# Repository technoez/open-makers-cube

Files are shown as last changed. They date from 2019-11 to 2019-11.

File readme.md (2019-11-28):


# OpenMakersCube

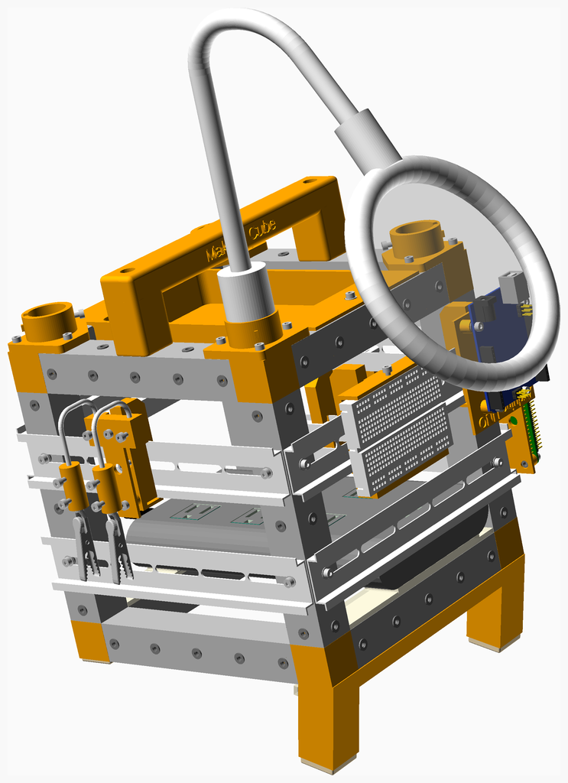
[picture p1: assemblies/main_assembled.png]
 <br>
**Open Maker's Cube** is an open source project developed for making electronics project design and testing more fun and convenient. Due to its versatile design, the Maker's Cube can be used for other hobbies and applications.

The itch needing scratching is the ratsnest of wires and cables generated when building electronics bread board circuits. I frequently use Raspberry Pis and other microcontrollers/SBCs.  With these devices comes the need for power strips which quickly leads to a maze of entangled power cords.

Portability of any electronics project can be an issue.  If a project is built on the kitchen table for example, relocating requires a lot of disconnecting and re-routing.  Inevetibly wires came loose from the breadboards, resulting in needless troubleshooting.

Ergonomically, bending over and wiring breadboard circuits for hours is hard on the back and neck.  Adequate Lighting can also be a concern.

The Maker's cube is lightweight. Around 3.5 lbs base unit only and is less than 7 lbs fully loaded with hardware(Rpi's/Arduinos, electronic components, plugin power supplies).

The dimensions are 200mm (8in.) x 200mm (8in.) x 200mm (8in.).  This size is perfect for any desk or table.  Not taking up any more space than a typical laptop.

The frame is made out of lightweight 1 in. square aluminum tubing. In early designs, 80/20 was used, but added almost 2x the weight.

M3 Threaded aluminum inserts are inserted into the aluminum frame to hold the components securely. The threaded inserts do require a rivet insertion tool. There are a lot of rivets, so inserting rivets into the frame is the most time consuming process. 

All plastic parts (orange) are printed with PETG. I went with PETG to hopefully withstand the heat better. Especially in the summer months. Obviously, print in any material to fit your needs.

There are mounting plates to support Raspberry PIs and Arduino UNOs in both landscape and portrait orientations.  Due to the flexibility of the DIN Rail clips, you can design any mounting plate for any device which can easily be attached to the DIN rail clips using two 2 - 3mm securing screws.

There is a mounting plate which holds a standard 400 pt solderless breadboard in both landscape and portrait orientations.

Mounted in the center of the Maker's cube is a 6 outlet power strip with 4 - 2.4A USB ports. This allows for mulitple electrical plugins inside the cube keeping the corded 'ratsnest' inside the body of the cube.  The power strip has an extra long 9.8 ft cord.

By design, only M3 screws are used.  This requires only a simple 2.5mm allen key, which I leave inside the tray.  The DIN rail mounting clips can normally be removed by hand.  However, if there are a lot of mounted components, the only other tool needed is a small flat tipped screwdriver to unlock the clips.

I use 6 inch plastic wire ties to keep the cables/wires organized inside the Maker's cube body.

There is a removable stand (prop) which is used to tilt the cube back at a 30 deg angle which allows the user to work at a comfortable eye level.

The detachable LED magnifier lamp is extremely handy.  It is super bright and having a magnifier lens makes it extremely easy to see the intricate details.

As an after thought, I designed a crude helping hands assembly.  It uses 3mm aluminum armature wire and conventional alligator clips.  This is helpful if you need to solder or hold components.  Yes, the wire will eventually break with excessive bending back-and-forth, but the wire is cheap and can be easily replaced. 

I use 3M's 'Dual Lock' fastener tape to secure the power supply to the inside bottom frame of the cube.  The allows the power supply to be easily removed if need be.  Also, the front 'prop' stand which tilts the cube at an angle, uses small sections of this tape to secure itself inside the cube's inner frame for transport.

To be extremely modular and flexible I designed the DIN Rail clips to be generic by nature. There two 3mm threaded inserts for mounting external components. The idea is you can design and mount anything you'd like to the clip.  

I began the CAD design work in Sketchup. However, since I wanted to release as a open source project, I migrated the CAD design over to [OpenScad](http://openscad.org).  I relied heavlily on these wonderful open source projects:  
1. [NopSCADlib](https://github.com/nophead/NopSCADlib/blob/master/readme.md) - nophead, thanks so much for contributing this library! Absolutely amazing and a huge time saver for generating this beautiful documentation.
2. [BOSL](https://github.com/revarbat/BOSL/wiki) 
3. [Dimlines - A dimensioning library](http://www.cannymachines.com/entries/9/openscad_dimensioned_drawings)
4. [objectarrays](https://github.com/mathcodeprint/openscad-fiddlybits/blob/master/objectarrays.scad)
5. [MCAD](https://github.com/openscad/MCAD)
6. [Obiscad](https://github.com/Obijuan/obiscad)
7. [Textgenerator](https://www.thingiverse.com/thing:59817)
8. [Shimonbox](https://github.com/ubitux/shimonbox)
9. [Openscad-threads](http://dkprojects.net/openscad-threads/)
10. [Chamfersfor OpenScad](https://github.com/SebiTimeWaster/Chamfers-for-OpenSCAD)
11. [BOLTS](https://www.bolts-library.org/en/index.html)
12. [Din Rail Inspiration](https://www.thingiverse.com/thing:101024) RobertHunt Thingiverse

Thank you to the authors of these libraries. I may not have used all them directly in this project, but have gained inspiration from all. 
I may have used other libraries which I have not given credit. If so, please contact me and I'll update the list. 
I'm relatively new to OpenScad programming, so my code is not perfect and not always fully parameterized.

In summary, Maker's Cube goal is to address the following concerns:
1. **Portability**
   Contain the electronics project in one location and easy to transport. A fully loaded cube weighs less than 6 lbs.
2. **Less back strain** 
   You can comfortably work on your projects in a seated position, eliminating the need to bend over a table/desk for hours.
3. **Less eye strain**
   There is a flexible super bright LED lamp mounted to the cube with a 1.5X magnifier glass.
4. **Modularity**
   Due to the Clip-on DIN Rail system, components can be easily re-positioned/removed from the cube.
5. **Project tidyness**
   A 6 outlet power strip with 4 - 2.4A USB ports is located inside the base of the cube. 
   This allows for mulitple electrical plugins inside the cube keeping the corded 'ratsnest' inside the body of the cube.

### Tools Required For Build:
1. 3D Printer
2. [Threaded Insert Rivet Gun w/3mm mandrel](https://www.amazon.com/gp/product/B06XVB3MMG/ref=ppx_yo_dt_b_search_asin_title?ie=UTF8&psc=1)
3. 2.5mm Allen Key
4. Saw to Cut 1 in. aluminum tubing.  Chopsaw, hacksaw, other.
5. Knife or razor blades
6. 5mm drill bit to drill holes for 3mm threaded inserts
7. Drill    
8. 3mm x .5mm hole tap.  To tap 3mm holes in 3D printed plastic.

### Parts List and Qty Per Build:
- [See Table Of Contents](readme.md#table-of-contents)

### Vendor List of Parts (aka vitamins):
- [M3 Threaded Rivet Inserts (bag 100pcs)](https://www.amazon.com/gp/product/B07HKK364C/ref=ppx_yo_dt_b_search_asin_title?ie=UTF8&psc=1)
- [Velcro - 3M Dual Lock 1in wide 6FT Long](https://www.amazon.com/gp/product/B07D2LYFM2/ref=ppx_yo_dt_b_search_asin_title?ie=UTF8&psc=1)
- [PETG Filament - Orange 1Kg (1080 FT long)](https://www.amazon.com/gp/product/B014VM9ALM/ref=ppx_yo_dt_b_asin_title_o00_s00?ie=UTF8&psc=1)
- [6 Outlet power strip (SuperDanny)](https://www.amazon.com/gp/product/B077ZSC6RQ/ref=ppx_yo_dt_b_search_asin_title?ie=UTF8&psc=1)
- [Breadboard - Half Size (pack 6 ea)](https://www.amazon.com/gp/product/B01NARN7SM/ref=ppx_yo_dt_b_search_asin_title?ie=UTF8&psc=1)
- [Rubber Bumpers (pack of 20 ea)](https://www.amazon.com/gp/product/B01G5WX4M2/ref=ppx_yo_dt_b_search_asin_title?ie=UTF8&psc=1)
- [Screws - M3 x 5 (pack of 100)](https://www.boltdepot.com/Product-Details.aspx?product=6377)
- [Screws - M3 x 8](https://www.boltdepot.com/Product-Details.aspx?product=6379)
- [Screws - M3 x 12](https://www.boltdepot.com/Product-Details.aspx?product=6381)
- [Screws - M3 x 16](https://www.boltdepot.com/Product-Details.aspx?product=6382)
- [Washers - M3](https://www.boltdepot.com/Product-Details.aspx?product=4513)
- [Magnifier Lamp](https://www.amazon.com/gp/product/B019R1BN3U/ref=ppx_yo_dt_b_search_asin_title?ie=UTF8&psc=1)
- [Armature Wire 3MM (32.8 ft copper/alum)](https://www.amazon.com/gp/product/B07CQL7Y5B/ref=ppx_yo_dt_b_search_asin_title?ie=UTF8&psc=1)
- [Tygon Tubing 50FT 1/8" OD (cover alligator clips)](https://www.zoro.com/tygon-tubing-clear-18-in-inside-dia-50-ft-acf00006/i/G4124294/)
- [Alligator Clips (Package of 50)](https://www.amazon.com/gp/product/B01D9BO4OO/ref=ppx_yo_dt_b_search_asin_title?ie=UTF8&psc=1)
- [Plastic Ties Blk 6 in (pk 250)](https://www.amazon.com/gp/product/B0718T3FMF/ref=ppx_yo_dt_b_search_asin_title?ie=UTF8&psc=1)
- [2.5MM Allen Wrench (pk 100)](https://www.amazon.com/gp/product/B005SE78Z8/ref=ppx_yo_dt_b_search_asin_title?ie=UTF8&psc=1)
- [Din Rails 200MM (20 Pak)](https://www.amazon.com/gp/product/B07HMW318D/ref=ppx_yo_dt_b_asin_title_o08_s00?ie=UTF8&psc=1)

### Picture Gallery 
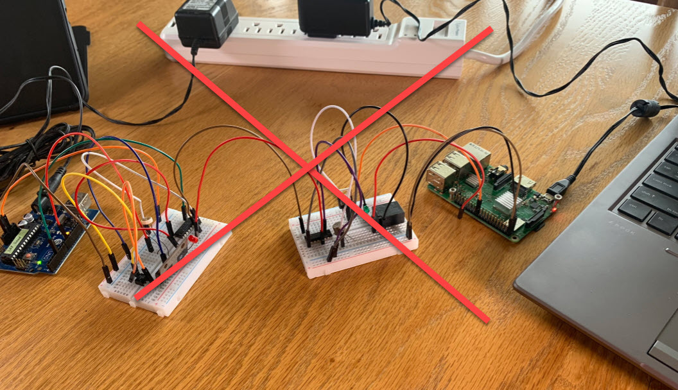
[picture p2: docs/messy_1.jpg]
- 
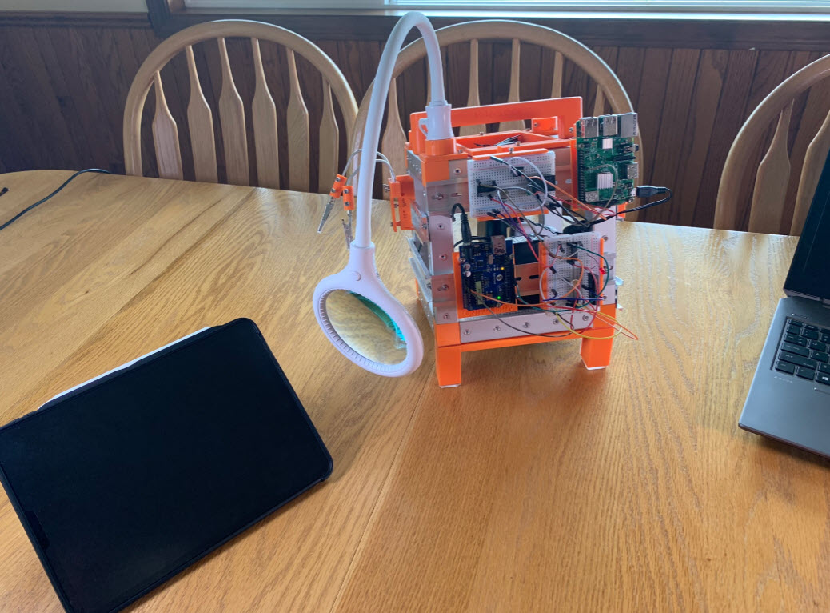
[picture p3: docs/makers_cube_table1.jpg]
- 
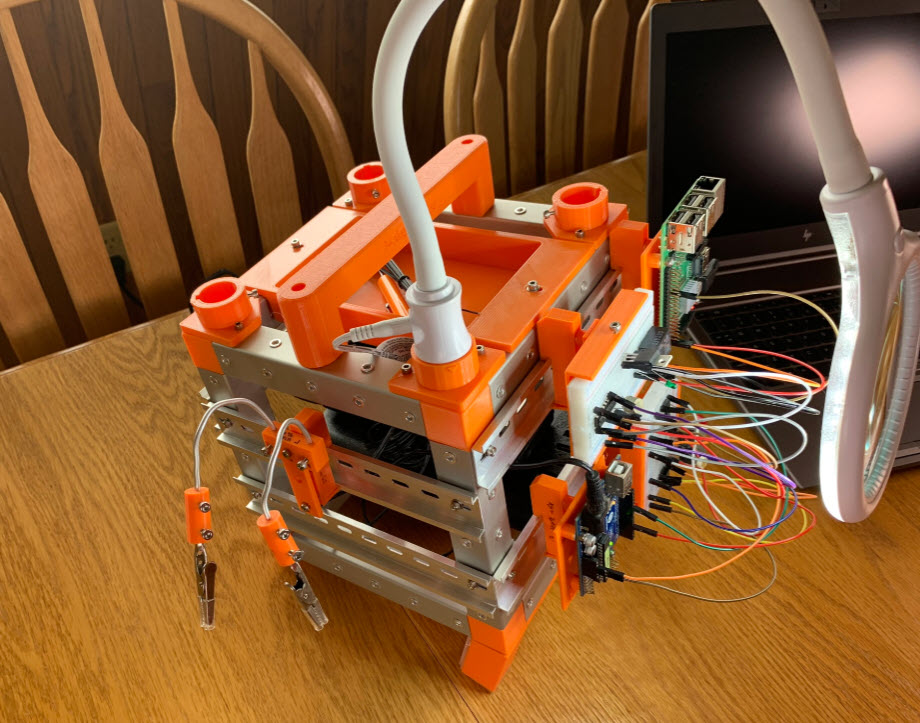
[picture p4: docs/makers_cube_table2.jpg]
- 
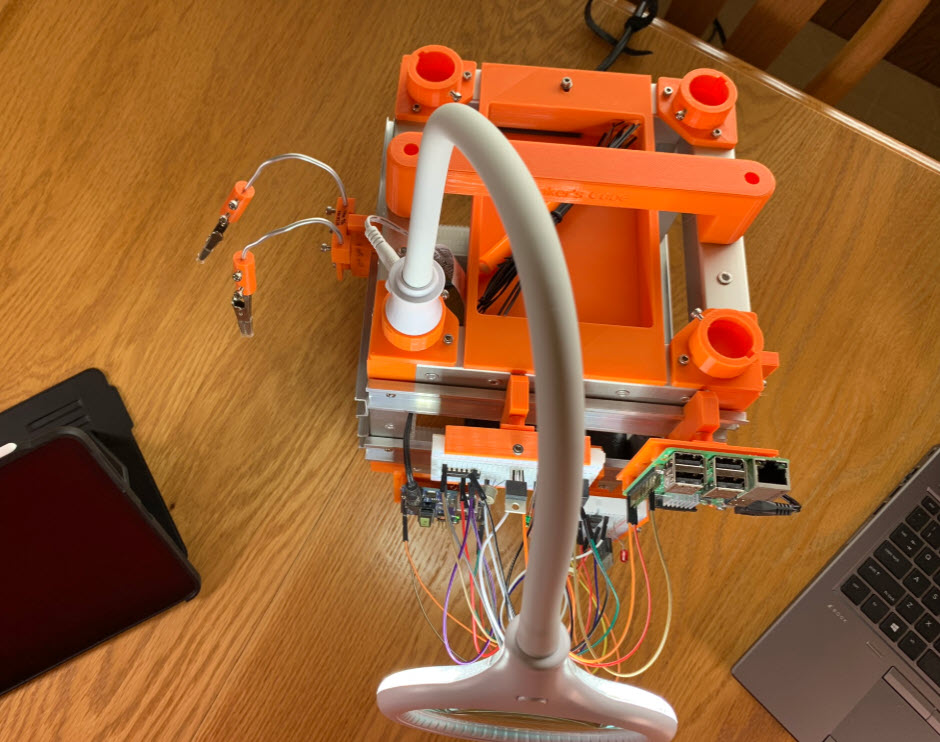
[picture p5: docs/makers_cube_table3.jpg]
- 
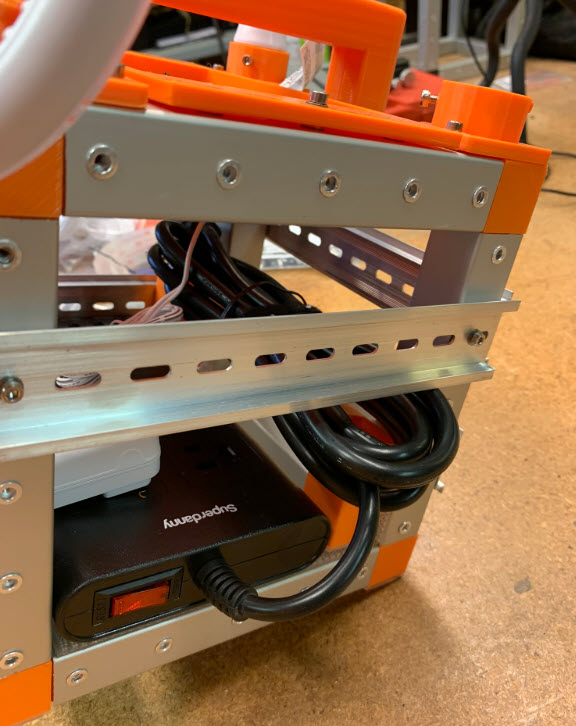
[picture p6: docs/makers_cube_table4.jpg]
- 
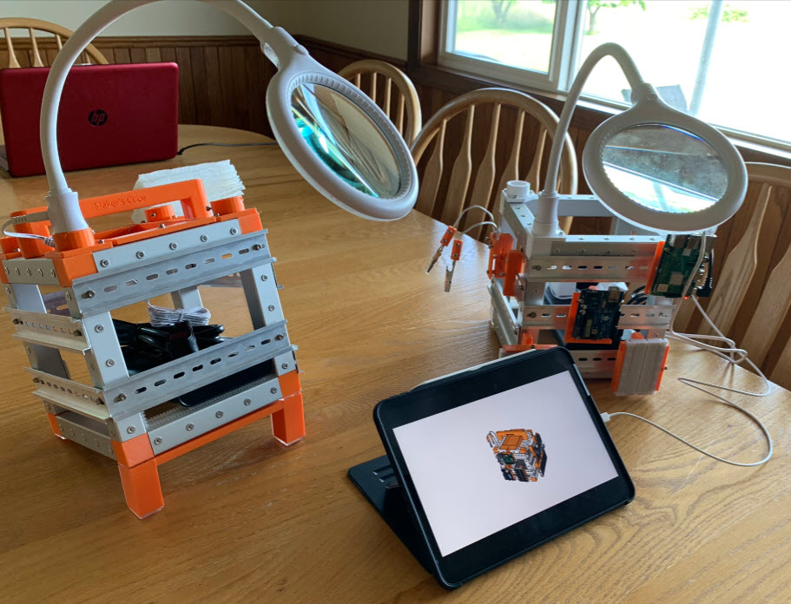
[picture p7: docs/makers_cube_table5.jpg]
- 
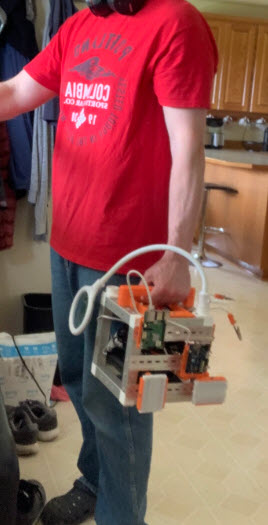
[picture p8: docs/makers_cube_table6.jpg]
- 

### 3D Printing
All of the STL models for this project are located in the /stls subdirectory.

Getting these prints correct was a highly iterative process.  Accuracy is the key to getting these components to fit properly.
Make sure your printer is calibrated and X/Y print scaling is correct.

### 3D Print Settings
<table>
<tr><th>STL</th><th>Resolution</th><th>Infill %</th><th>Supports</th><th>Comments</th></tr>
<tr><td>arduino_uno_mounting_plate.stl</td><td align="center">.3</td><td align="center">20</td><td align="center">NO</td><td>STL file located in <b>/stls</b> directory</td></tr>
<tr><td>armature_union.stl</td><td align="center">.3</td><td align="center">100</td><td align="center">NO</td><td>STL file located in <b>/stls</b> directory</td></tr>
<tr><td>back_spin_plate.stl</td><td align="center">.3</td><td align="center">20</td><td align="center">NO</td><td>STL file located in <b>/stls</b> directory</td></tr>
<tr><td>carry_handle.stl</td><td align="center">.3</td><td align="center">20</td><td align="center">NO</td><td>STL file located in <b>/stls</b> directory</td></tr>
<tr><td>corner_tube_connector_bottom.stl</td><td align="center">.3</td><td align="center">20</td><td align="center"><b>YES</b></td><td>STL file located in <b>/stls</b> directory</td></tr>
<tr><td>corner_tube_connector_bottom_v2.stl</td><td align="center">.3</td><td align="center">20</td><td align="center">NO</td><td>Alternate print orientation not requiring supports and stronger. STL file located in <b>/docs</b> directory</td></tr>
<tr><td>corner_tube_connector_top.stl</td><td align="center">.3</td><td align="center">20</td><td align="center"><b>YES</b></td><td>STL file located in <b>/stls</b> directory</td></tr>
<tr><td>corner_tube_connector_top_v2.stl</td><td align="center">.3</td><td align="center">20</td><td align="center">NO</td><td>Alternate print orientation not requiring supports and stronger. STL file located in <b>/docs</b> directory</td></tr>
<tr><td>din_rail_clip.stl</td><td align="center">.3</td><td align="center">100</td><td align="center">NO</td><td>STL file located in <b>/stls</b> directory</td></tr>
<tr><td>helping_hands_mount.stl</td><td align="center">.3</td><td align="center">20</td><td align="center">NO</td><td>STL file located in <b>/stls</b> directory</td></tr>
<tr><td>prop.stl</td><td align="center">.3</td><td align="center">20</td><td align="center">NO</td><td>STL file located in <b>/stls</b> directory</td></tr>
<tr><td>raspberry_pi_mounting_plate.stl</td><td align="center">.3</td><td align="center">20</td><td align="center">NO</td><td>STL file located in <b>/stls</b> directory</td></tr>
<tr><td>small_breadboard_holder.stl</td><td align="center">.3</td><td align="center">20</td><td align="center">NO</td><td>STL file located in <b>/stls</b> directory</td></tr>
</table>

Main Assembly

---
## Table of Contents
1. [Parts list](#Parts_list)
1. [Prop Assembly](#prop_assembly)
1. [Power Strip Assembly](#power_strip_assembly)
1. [Tray Assembly](#tray_assembly)
1. [Corner Lamp Holder Assembly](#corner_lamp_holder_assembly)
1. [Din Rail Clip Assembly](#din_rail_clip_assembly)
1. [Back Spin Plate Assembly](#back_spin_plate_assembly)
1. [Raspberry Pi Mounting Plate Portrait Assembly](#raspberry_pi_mounting_plate_portrait_assembly)
1. [Arduino Uno Mounting Plate Portrait Assembly](#arduino_uno_mounting_plate_portrait_assembly)
1. [Small Breadboard Portrait Assembly](#small_breadboard_portrait_assembly)
1. [Small Breadboard Landscape Assembly](#small_breadboard_landscape_assembly)
1. [Carry Handle Assembly](#carry_handle_assembly)
1. [Din Rail Assembly](#din_rail_assembly)
1. [Corner Tube Top Assembly](#corner_tube_top_assembly)
1. [Frame Bottom Assembly](#frame_bottom_assembly)
1. [Frame Middle Assembly](#frame_middle_assembly)
1. [Frame Top Assembly](#frame_top_assembly)
1. [Frame Assembly](#frame_assembly)
1. [Helping Hands Assembly](#helping_hands_assembly)
1. [Main Assembly](#main_assembly)

[Top](#TOP)

---

## Parts list
| <span style="writing-mode: vertical-rl; text-orientation: mixed;">Prop</span> | <span style="writing-mode: vertical-rl; text-orientation: mixed;">Power&nbsp;Strip</span> | <span style="writing-mode: vertical-rl; text-orientation: mixed;">Tray</span> | <span style="writing-mode: vertical-rl; text-orientation: mixed;">Corner&nbsp;Lamp&nbsp;Holder</span> | <span style="writing-mode: vertical-rl; text-orientation: mixed;">Din&nbsp;Rail&nbsp;Clip</span> | <span style="writing-mode: vertical-rl; text-orientation: mixed;">Back&nbsp;Spin&nbsp;Plate</span> | <span style="writing-mode: vertical-rl; text-orientation: mixed;">Raspberry&nbsp;Pi&nbsp;Mounting&nbsp;Plate&nbsp;Portrait</span> | <span style="writing-mode: vertical-rl; text-orientation: mixed;">Arduino&nbsp;Uno&nbsp;Mounting&nbsp;Plate&nbsp;Portrait</span> | <span style="writing-mode: vertical-rl; text-orientation: mixed;">Small&nbsp;Breadboard&nbsp;Portrait</span> | <span style="writing-mode: vertical-rl; text-orientation: mixed;">Small&nbsp;Breadboard&nbsp;Landscape</span> | <span style="writing-mode: vertical-rl; text-orientation: mixed;">Carry&nbsp;Handle</span> | <span style="writing-mode: vertical-rl; text-orientation: mixed;">Din&nbsp;Rail</span> | <span style="writing-mode: vertical-rl; text-orientation: mixed;">Corner&nbsp;Tube&nbsp;Top</span> | <span style="writing-mode: vertical-rl; text-orientation: mixed;">Frame&nbsp;Bottom</span> | <span style="writing-mode: vertical-rl; text-orientation: mixed;">Frame&nbsp;Middle</span> | <span style="writing-mode: vertical-rl; text-orientation: mixed;">Frame&nbsp;Top</span> | <span style="writing-mode: vertical-rl; text-orientation: mixed;">Frame</span> | <span style="writing-mode: vertical-rl; text-orientation: mixed;">Helping&nbsp;Hands</span> | <span style="writing-mode: vertical-rl; text-orientation: mixed;">Main</span> | <span style="writing-mode: vertical-rl; text-orientation: mixed;">TOTALS</span> |  |
|--:|--:|--:|--:|--:|--:|--:|--:|--:|--:|--:|--:|--:|--:|--:|--:|--:|--:|--:|--:|:--|
| &nbsp;&nbsp;.&nbsp; | &nbsp;&nbsp;.&nbsp; | &nbsp;&nbsp;.&nbsp; | &nbsp;&nbsp;.&nbsp; | &nbsp;&nbsp;.&nbsp; | &nbsp;&nbsp;.&nbsp; | &nbsp;&nbsp;.&nbsp; | &nbsp;&nbsp;.&nbsp; | &nbsp;&nbsp;.&nbsp; | &nbsp;&nbsp;.&nbsp; | &nbsp;&nbsp;.&nbsp; | &nbsp;&nbsp;.&nbsp; | &nbsp;&nbsp;.&nbsp; | &nbsp;&nbsp;.&nbsp; | &nbsp;&nbsp;.&nbsp; | &nbsp;&nbsp;.&nbsp; | &nbsp;&nbsp;.&nbsp; | &nbsp;&nbsp;.&nbsp; | &nbsp;&nbsp;2&nbsp; |  &nbsp;&nbsp;2&nbsp; | &nbsp;&nbsp;  3M Dual lock velcro 149mm long |
| &nbsp;&nbsp;2&nbsp; | &nbsp;&nbsp;.&nbsp; | &nbsp;&nbsp;.&nbsp; | &nbsp;&nbsp;.&nbsp; | &nbsp;&nbsp;.&nbsp; | &nbsp;&nbsp;.&nbsp; | &nbsp;&nbsp;.&nbsp; | &nbsp;&nbsp;.&nbsp; | &nbsp;&nbsp;.&nbsp; | &nbsp;&nbsp;.&nbsp; | &nbsp;&nbsp;.&nbsp; | &nbsp;&nbsp;.&nbsp; | &nbsp;&nbsp;.&nbsp; | &nbsp;&nbsp;.&nbsp; | &nbsp;&nbsp;.&nbsp; | &nbsp;&nbsp;.&nbsp; | &nbsp;&nbsp;.&nbsp; | &nbsp;&nbsp;.&nbsp; | &nbsp;&nbsp;2&nbsp; |  &nbsp;&nbsp;4&nbsp; | &nbsp;&nbsp;  3M Dual lock velcro 6mm long |
| &nbsp;&nbsp;.&nbsp; | &nbsp;&nbsp;2&nbsp; | &nbsp;&nbsp;.&nbsp; | &nbsp;&nbsp;.&nbsp; | &nbsp;&nbsp;.&nbsp; | &nbsp;&nbsp;.&nbsp; | &nbsp;&nbsp;.&nbsp; | &nbsp;&nbsp;.&nbsp; | &nbsp;&nbsp;.&nbsp; | &nbsp;&nbsp;.&nbsp; | &nbsp;&nbsp;.&nbsp; | &nbsp;&nbsp;.&nbsp; | &nbsp;&nbsp;.&nbsp; | &nbsp;&nbsp;.&nbsp; | &nbsp;&nbsp;.&nbsp; | &nbsp;&nbsp;.&nbsp; | &nbsp;&nbsp;.&nbsp; | &nbsp;&nbsp;.&nbsp; | &nbsp;&nbsp;.&nbsp; |  &nbsp;&nbsp;2&nbsp; | &nbsp;&nbsp;  3M Dual lock velcro 85mm long |
| &nbsp;&nbsp;.&nbsp; | &nbsp;&nbsp;1&nbsp; | &nbsp;&nbsp;.&nbsp; | &nbsp;&nbsp;.&nbsp; | &nbsp;&nbsp;.&nbsp; | &nbsp;&nbsp;.&nbsp; | &nbsp;&nbsp;.&nbsp; | &nbsp;&nbsp;.&nbsp; | &nbsp;&nbsp;.&nbsp; | &nbsp;&nbsp;.&nbsp; | &nbsp;&nbsp;.&nbsp; | &nbsp;&nbsp;.&nbsp; | &nbsp;&nbsp;.&nbsp; | &nbsp;&nbsp;.&nbsp; | &nbsp;&nbsp;.&nbsp; | &nbsp;&nbsp;.&nbsp; | &nbsp;&nbsp;.&nbsp; | &nbsp;&nbsp;.&nbsp; | &nbsp;&nbsp;.&nbsp; |  &nbsp;&nbsp;1&nbsp; | &nbsp;&nbsp;  Super Danny 6 outlet Power Strip |
| &nbsp;&nbsp;2&nbsp; | &nbsp;&nbsp;.&nbsp; | &nbsp;&nbsp;.&nbsp; | &nbsp;&nbsp;.&nbsp; | &nbsp;&nbsp;.&nbsp; | &nbsp;&nbsp;.&nbsp; | &nbsp;&nbsp;.&nbsp; | &nbsp;&nbsp;.&nbsp; | &nbsp;&nbsp;.&nbsp; | &nbsp;&nbsp;.&nbsp; | &nbsp;&nbsp;.&nbsp; | &nbsp;&nbsp;.&nbsp; | &nbsp;&nbsp;.&nbsp; | &nbsp;&nbsp;.&nbsp; | &nbsp;&nbsp;.&nbsp; | &nbsp;&nbsp;.&nbsp; | &nbsp;&nbsp;.&nbsp; | &nbsp;&nbsp;.&nbsp; | &nbsp;&nbsp;4&nbsp; |  &nbsp;&nbsp;6&nbsp; | &nbsp;&nbsp; 1 inch sq rubber foot |
| &nbsp;&nbsp;.&nbsp; | &nbsp;&nbsp;.&nbsp; | &nbsp;&nbsp;.&nbsp; | &nbsp;&nbsp;.&nbsp; | &nbsp;&nbsp;.&nbsp; | &nbsp;&nbsp;.&nbsp; | &nbsp;&nbsp;.&nbsp; | &nbsp;&nbsp;.&nbsp; | &nbsp;&nbsp;.&nbsp; | &nbsp;&nbsp;.&nbsp; | &nbsp;&nbsp;.&nbsp; | &nbsp;&nbsp;.&nbsp; | &nbsp;&nbsp;.&nbsp; | &nbsp;&nbsp;4&nbsp; | &nbsp;&nbsp;4&nbsp; | &nbsp;&nbsp;4&nbsp; | &nbsp;&nbsp;.&nbsp; | &nbsp;&nbsp;.&nbsp; | &nbsp;&nbsp;.&nbsp; |  &nbsp;&nbsp;12&nbsp; | &nbsp;&nbsp; 1IN Aluminum Square Tube 149.2 MM long |
| &nbsp;&nbsp;.&nbsp; | &nbsp;&nbsp;.&nbsp; | &nbsp;&nbsp;.&nbsp; | &nbsp;&nbsp;.&nbsp; | &nbsp;&nbsp;.&nbsp; | &nbsp;&nbsp;.&nbsp; | &nbsp;&nbsp;.&nbsp; | &nbsp;&nbsp;.&nbsp; | &nbsp;&nbsp;.&nbsp; | &nbsp;&nbsp;.&nbsp; | &nbsp;&nbsp;.&nbsp; | &nbsp;&nbsp;7&nbsp; | &nbsp;&nbsp;.&nbsp; | &nbsp;&nbsp;.&nbsp; | &nbsp;&nbsp;.&nbsp; | &nbsp;&nbsp;.&nbsp; | &nbsp;&nbsp;.&nbsp; | &nbsp;&nbsp;.&nbsp; | &nbsp;&nbsp;.&nbsp; |  &nbsp;&nbsp;7&nbsp; | &nbsp;&nbsp; 35MM Din Rail 200 MM long |
| &nbsp;&nbsp;.&nbsp; | &nbsp;&nbsp;.&nbsp; | &nbsp;&nbsp;.&nbsp; | &nbsp;&nbsp;.&nbsp; | &nbsp;&nbsp;.&nbsp; | &nbsp;&nbsp;.&nbsp; | &nbsp;&nbsp;.&nbsp; | &nbsp;&nbsp;.&nbsp; | &nbsp;&nbsp;.&nbsp; | &nbsp;&nbsp;.&nbsp; | &nbsp;&nbsp;.&nbsp; | &nbsp;&nbsp;.&nbsp; | &nbsp;&nbsp;.&nbsp; | &nbsp;&nbsp;.&nbsp; | &nbsp;&nbsp;.&nbsp; | &nbsp;&nbsp;.&nbsp; | &nbsp;&nbsp;.&nbsp; | &nbsp;&nbsp;2&nbsp; | &nbsp;&nbsp;.&nbsp; |  &nbsp;&nbsp;2&nbsp; | &nbsp;&nbsp; 3MM Armature wire - 5 inches long |
| &nbsp;&nbsp;.&nbsp; | &nbsp;&nbsp;.&nbsp; | &nbsp;&nbsp;.&nbsp; | &nbsp;&nbsp;.&nbsp; | &nbsp;&nbsp;8&nbsp; | &nbsp;&nbsp;8&nbsp; | &nbsp;&nbsp;4&nbsp; | &nbsp;&nbsp;4&nbsp; | &nbsp;&nbsp;.&nbsp; | &nbsp;&nbsp;.&nbsp; | &nbsp;&nbsp;.&nbsp; | &nbsp;&nbsp;.&nbsp; | &nbsp;&nbsp;4&nbsp; | &nbsp;&nbsp;20&nbsp; | &nbsp;&nbsp;40&nbsp; | &nbsp;&nbsp;40&nbsp; | &nbsp;&nbsp;.&nbsp; | &nbsp;&nbsp;.&nbsp; | &nbsp;&nbsp;.&nbsp; |  &nbsp;&nbsp;128&nbsp; | &nbsp;&nbsp; 3MM threaded rivet insert |
| &nbsp;&nbsp;.&nbsp; | &nbsp;&nbsp;.&nbsp; | &nbsp;&nbsp;.&nbsp; | &nbsp;&nbsp;.&nbsp; | &nbsp;&nbsp;.&nbsp; | &nbsp;&nbsp;.&nbsp; | &nbsp;&nbsp;.&nbsp; | &nbsp;&nbsp;.&nbsp; | &nbsp;&nbsp;.&nbsp; | &nbsp;&nbsp;.&nbsp; | &nbsp;&nbsp;.&nbsp; | &nbsp;&nbsp;.&nbsp; | &nbsp;&nbsp;.&nbsp; | &nbsp;&nbsp;.&nbsp; | &nbsp;&nbsp;.&nbsp; | &nbsp;&nbsp;.&nbsp; | &nbsp;&nbsp;.&nbsp; | &nbsp;&nbsp;2&nbsp; | &nbsp;&nbsp;.&nbsp; |  &nbsp;&nbsp;2&nbsp; | &nbsp;&nbsp; Alligator Clip |
| &nbsp;&nbsp;.&nbsp; | &nbsp;&nbsp;.&nbsp; | &nbsp;&nbsp;.&nbsp; | &nbsp;&nbsp;.&nbsp; | &nbsp;&nbsp;.&nbsp; | &nbsp;&nbsp;.&nbsp; | &nbsp;&nbsp;.&nbsp; | &nbsp;&nbsp;1&nbsp; | &nbsp;&nbsp;.&nbsp; | &nbsp;&nbsp;.&nbsp; | &nbsp;&nbsp;.&nbsp; | &nbsp;&nbsp;.&nbsp; | &nbsp;&nbsp;.&nbsp; | &nbsp;&nbsp;.&nbsp; | &nbsp;&nbsp;.&nbsp; | &nbsp;&nbsp;.&nbsp; | &nbsp;&nbsp;.&nbsp; | &nbsp;&nbsp;.&nbsp; | &nbsp;&nbsp;.&nbsp; |  &nbsp;&nbsp;1&nbsp; | &nbsp;&nbsp; Arduino Uno R3 |
| &nbsp;&nbsp;.&nbsp; | &nbsp;&nbsp;.&nbsp; | &nbsp;&nbsp;.&nbsp; | &nbsp;&nbsp;.&nbsp; | &nbsp;&nbsp;.&nbsp; | &nbsp;&nbsp;.&nbsp; | &nbsp;&nbsp;.&nbsp; | &nbsp;&nbsp;.&nbsp; | &nbsp;&nbsp;.&nbsp; | &nbsp;&nbsp;.&nbsp; | &nbsp;&nbsp;.&nbsp; | &nbsp;&nbsp;.&nbsp; | &nbsp;&nbsp;.&nbsp; | &nbsp;&nbsp;.&nbsp; | &nbsp;&nbsp;.&nbsp; | &nbsp;&nbsp;.&nbsp; | &nbsp;&nbsp;.&nbsp; | &nbsp;&nbsp;.&nbsp; | &nbsp;&nbsp;1&nbsp; |  &nbsp;&nbsp;1&nbsp; | &nbsp;&nbsp; Magnifier Lamp Assembly |
| &nbsp;&nbsp;.&nbsp; | &nbsp;&nbsp;.&nbsp; | &nbsp;&nbsp;.&nbsp; | &nbsp;&nbsp;.&nbsp; | &nbsp;&nbsp;.&nbsp; | &nbsp;&nbsp;.&nbsp; | &nbsp;&nbsp;1&nbsp; | &nbsp;&nbsp;.&nbsp; | &nbsp;&nbsp;.&nbsp; | &nbsp;&nbsp;.&nbsp; | &nbsp;&nbsp;.&nbsp; | &nbsp;&nbsp;.&nbsp; | &nbsp;&nbsp;.&nbsp; | &nbsp;&nbsp;.&nbsp; | &nbsp;&nbsp;.&nbsp; | &nbsp;&nbsp;.&nbsp; | &nbsp;&nbsp;.&nbsp; | &nbsp;&nbsp;.&nbsp; | &nbsp;&nbsp;.&nbsp; |  &nbsp;&nbsp;1&nbsp; | &nbsp;&nbsp; Micro SD card |
| &nbsp;&nbsp;.&nbsp; | &nbsp;&nbsp;.&nbsp; | &nbsp;&nbsp;.&nbsp; | &nbsp;&nbsp;.&nbsp; | &nbsp;&nbsp;.&nbsp; | &nbsp;&nbsp;.&nbsp; | &nbsp;&nbsp;1&nbsp; | &nbsp;&nbsp;.&nbsp; | &nbsp;&nbsp;.&nbsp; | &nbsp;&nbsp;.&nbsp; | &nbsp;&nbsp;.&nbsp; | &nbsp;&nbsp;.&nbsp; | &nbsp;&nbsp;.&nbsp; | &nbsp;&nbsp;.&nbsp; | &nbsp;&nbsp;.&nbsp; | &nbsp;&nbsp;.&nbsp; | &nbsp;&nbsp;.&nbsp; | &nbsp;&nbsp;.&nbsp; | &nbsp;&nbsp;.&nbsp; |  &nbsp;&nbsp;1&nbsp; | &nbsp;&nbsp; Raspberry Pi 3 |
| &nbsp;&nbsp;.&nbsp; | &nbsp;&nbsp;.&nbsp; | &nbsp;&nbsp;2&nbsp; | &nbsp;&nbsp;12&nbsp; | &nbsp;&nbsp;.&nbsp; | &nbsp;&nbsp;.&nbsp; | &nbsp;&nbsp;2&nbsp; | &nbsp;&nbsp;2&nbsp; | &nbsp;&nbsp;2&nbsp; | &nbsp;&nbsp;2&nbsp; | &nbsp;&nbsp;.&nbsp; | &nbsp;&nbsp;.&nbsp; | &nbsp;&nbsp;.&nbsp; | &nbsp;&nbsp;.&nbsp; | &nbsp;&nbsp;.&nbsp; | &nbsp;&nbsp;.&nbsp; | &nbsp;&nbsp;.&nbsp; | &nbsp;&nbsp;2&nbsp; | &nbsp;&nbsp;.&nbsp; |  &nbsp;&nbsp;24&nbsp; | &nbsp;&nbsp; Screw M3 cap x 12mm |
| &nbsp;&nbsp;.&nbsp; | &nbsp;&nbsp;.&nbsp; | &nbsp;&nbsp;.&nbsp; | &nbsp;&nbsp;.&nbsp; | &nbsp;&nbsp;.&nbsp; | &nbsp;&nbsp;.&nbsp; | &nbsp;&nbsp;1&nbsp; | &nbsp;&nbsp;1&nbsp; | &nbsp;&nbsp;1&nbsp; | &nbsp;&nbsp;1&nbsp; | &nbsp;&nbsp;2&nbsp; | &nbsp;&nbsp;.&nbsp; | &nbsp;&nbsp;.&nbsp; | &nbsp;&nbsp;.&nbsp; | &nbsp;&nbsp;.&nbsp; | &nbsp;&nbsp;.&nbsp; | &nbsp;&nbsp;.&nbsp; | &nbsp;&nbsp;1&nbsp; | &nbsp;&nbsp;.&nbsp; |  &nbsp;&nbsp;7&nbsp; | &nbsp;&nbsp; Screw M3 cap x 16mm |
| &nbsp;&nbsp;.&nbsp; | &nbsp;&nbsp;.&nbsp; | &nbsp;&nbsp;.&nbsp; | &nbsp;&nbsp;.&nbsp; | &nbsp;&nbsp;.&nbsp; | &nbsp;&nbsp;.&nbsp; | &nbsp;&nbsp;.&nbsp; | &nbsp;&nbsp;.&nbsp; | &nbsp;&nbsp;1&nbsp; | &nbsp;&nbsp;1&nbsp; | &nbsp;&nbsp;.&nbsp; | &nbsp;&nbsp;.&nbsp; | &nbsp;&nbsp;.&nbsp; | &nbsp;&nbsp;.&nbsp; | &nbsp;&nbsp;.&nbsp; | &nbsp;&nbsp;.&nbsp; | &nbsp;&nbsp;.&nbsp; | &nbsp;&nbsp;.&nbsp; | &nbsp;&nbsp;.&nbsp; |  &nbsp;&nbsp;2&nbsp; | &nbsp;&nbsp; Screw M3 cap x 5mm |
| &nbsp;&nbsp;.&nbsp; | &nbsp;&nbsp;.&nbsp; | &nbsp;&nbsp;.&nbsp; | &nbsp;&nbsp;4&nbsp; | &nbsp;&nbsp;.&nbsp; | &nbsp;&nbsp;.&nbsp; | &nbsp;&nbsp;6&nbsp; | &nbsp;&nbsp;6&nbsp; | &nbsp;&nbsp;2&nbsp; | &nbsp;&nbsp;2&nbsp; | &nbsp;&nbsp;.&nbsp; | &nbsp;&nbsp;14&nbsp; | &nbsp;&nbsp;.&nbsp; | &nbsp;&nbsp;.&nbsp; | &nbsp;&nbsp;.&nbsp; | &nbsp;&nbsp;.&nbsp; | &nbsp;&nbsp;.&nbsp; | &nbsp;&nbsp;6&nbsp; | &nbsp;&nbsp;.&nbsp; |  &nbsp;&nbsp;40&nbsp; | &nbsp;&nbsp; Screw M3 cap x 8mm |
| &nbsp;&nbsp;.&nbsp; | &nbsp;&nbsp;.&nbsp; | &nbsp;&nbsp;.&nbsp; | &nbsp;&nbsp;.&nbsp; | &nbsp;&nbsp;.&nbsp; | &nbsp;&nbsp;.&nbsp; | &nbsp;&nbsp;.&nbsp; | &nbsp;&nbsp;.&nbsp; | &nbsp;&nbsp;1&nbsp; | &nbsp;&nbsp;1&nbsp; | &nbsp;&nbsp;.&nbsp; | &nbsp;&nbsp;.&nbsp; | &nbsp;&nbsp;.&nbsp; | &nbsp;&nbsp;.&nbsp; | &nbsp;&nbsp;.&nbsp; | &nbsp;&nbsp;.&nbsp; | &nbsp;&nbsp;.&nbsp; | &nbsp;&nbsp;.&nbsp; | &nbsp;&nbsp;.&nbsp; |  &nbsp;&nbsp;2&nbsp; | &nbsp;&nbsp; Small Breadboard |
| &nbsp;&nbsp;.&nbsp; | &nbsp;&nbsp;.&nbsp; | &nbsp;&nbsp;2&nbsp; | &nbsp;&nbsp;.&nbsp; | &nbsp;&nbsp;.&nbsp; | &nbsp;&nbsp;.&nbsp; | &nbsp;&nbsp;.&nbsp; | &nbsp;&nbsp;.&nbsp; | &nbsp;&nbsp;.&nbsp; | &nbsp;&nbsp;.&nbsp; | &nbsp;&nbsp;2&nbsp; | &nbsp;&nbsp;14&nbsp; | &nbsp;&nbsp;.&nbsp; | &nbsp;&nbsp;.&nbsp; | &nbsp;&nbsp;.&nbsp; | &nbsp;&nbsp;.&nbsp; | &nbsp;&nbsp;.&nbsp; | &nbsp;&nbsp;.&nbsp; | &nbsp;&nbsp;.&nbsp; |  &nbsp;&nbsp;18&nbsp; | &nbsp;&nbsp; Washer  M3 x 7mm x 0.5mm |
|  |  |  |  |  |  |  |  |  |  |  |  |  |  |  |  |  |  |  | | **3D Printed parts** |
| &nbsp;&nbsp;.&nbsp; | &nbsp;&nbsp;.&nbsp; | &nbsp;&nbsp;.&nbsp; | &nbsp;&nbsp;.&nbsp; | &nbsp;&nbsp;.&nbsp; | &nbsp;&nbsp;.&nbsp; | &nbsp;&nbsp;.&nbsp; | &nbsp;&nbsp;1&nbsp; | &nbsp;&nbsp;.&nbsp; | &nbsp;&nbsp;.&nbsp; | &nbsp;&nbsp;.&nbsp; | &nbsp;&nbsp;.&nbsp; | &nbsp;&nbsp;.&nbsp; | &nbsp;&nbsp;.&nbsp; | &nbsp;&nbsp;.&nbsp; | &nbsp;&nbsp;.&nbsp; | &nbsp;&nbsp;.&nbsp; | &nbsp;&nbsp;.&nbsp; | &nbsp;&nbsp;.&nbsp; | &nbsp;&nbsp;1&nbsp; | &nbsp;&nbsp;&nbsp;arduino_uno_mounting_plate.stl |
| &nbsp;&nbsp;.&nbsp; | &nbsp;&nbsp;.&nbsp; | &nbsp;&nbsp;.&nbsp; | &nbsp;&nbsp;.&nbsp; | &nbsp;&nbsp;.&nbsp; | &nbsp;&nbsp;.&nbsp; | &nbsp;&nbsp;.&nbsp; | &nbsp;&nbsp;.&nbsp; | &nbsp;&nbsp;.&nbsp; | &nbsp;&nbsp;.&nbsp; | &nbsp;&nbsp;.&nbsp; | &nbsp;&nbsp;.&nbsp; | &nbsp;&nbsp;.&nbsp; | &nbsp;&nbsp;.&nbsp; | &nbsp;&nbsp;.&nbsp; | &nbsp;&nbsp;.&nbsp; | &nbsp;&nbsp;.&nbsp; | &nbsp;&nbsp;2&nbsp; | &nbsp;&nbsp;.&nbsp; | &nbsp;&nbsp;2&nbsp; | &nbsp;&nbsp;&nbsp;armature_union.stl |
| &nbsp;&nbsp;.&nbsp; | &nbsp;&nbsp;.&nbsp; | &nbsp;&nbsp;.&nbsp; | &nbsp;&nbsp;.&nbsp; | &nbsp;&nbsp;.&nbsp; | &nbsp;&nbsp;4&nbsp; | &nbsp;&nbsp;.&nbsp; | &nbsp;&nbsp;.&nbsp; | &nbsp;&nbsp;.&nbsp; | &nbsp;&nbsp;.&nbsp; | &nbsp;&nbsp;.&nbsp; | &nbsp;&nbsp;.&nbsp; | &nbsp;&nbsp;.&nbsp; | &nbsp;&nbsp;.&nbsp; | &nbsp;&nbsp;.&nbsp; | &nbsp;&nbsp;.&nbsp; | &nbsp;&nbsp;.&nbsp; | &nbsp;&nbsp;.&nbsp; | &nbsp;&nbsp;.&nbsp; | &nbsp;&nbsp;4&nbsp; | &nbsp;&nbsp;&nbsp;back_spin_plate.stl |
| &nbsp;&nbsp;.&nbsp; | &nbsp;&nbsp;.&nbsp; | &nbsp;&nbsp;.&nbsp; | &nbsp;&nbsp;.&nbsp; | &nbsp;&nbsp;.&nbsp; | &nbsp;&nbsp;.&nbsp; | &nbsp;&nbsp;.&nbsp; | &nbsp;&nbsp;.&nbsp; | &nbsp;&nbsp;.&nbsp; | &nbsp;&nbsp;.&nbsp; | &nbsp;&nbsp;1&nbsp; | &nbsp;&nbsp;.&nbsp; | &nbsp;&nbsp;.&nbsp; | &nbsp;&nbsp;.&nbsp; | &nbsp;&nbsp;.&nbsp; | &nbsp;&nbsp;.&nbsp; | &nbsp;&nbsp;.&nbsp; | &nbsp;&nbsp;.&nbsp; | &nbsp;&nbsp;.&nbsp; | &nbsp;&nbsp;1&nbsp; | &nbsp;&nbsp;&nbsp;carry_handle.stl |
| &nbsp;&nbsp;.&nbsp; | &nbsp;&nbsp;.&nbsp; | &nbsp;&nbsp;.&nbsp; | &nbsp;&nbsp;.&nbsp; | &nbsp;&nbsp;.&nbsp; | &nbsp;&nbsp;.&nbsp; | &nbsp;&nbsp;.&nbsp; | &nbsp;&nbsp;.&nbsp; | &nbsp;&nbsp;.&nbsp; | &nbsp;&nbsp;.&nbsp; | &nbsp;&nbsp;.&nbsp; | &nbsp;&nbsp;.&nbsp; | &nbsp;&nbsp;.&nbsp; | &nbsp;&nbsp;.&nbsp; | &nbsp;&nbsp;.&nbsp; | &nbsp;&nbsp;.&nbsp; | &nbsp;&nbsp;4&nbsp; | &nbsp;&nbsp;.&nbsp; | &nbsp;&nbsp;.&nbsp; | &nbsp;&nbsp;4&nbsp; | &nbsp;&nbsp;&nbsp;corner_tube_connector_bottom.stl |
| &nbsp;&nbsp;.&nbsp; | &nbsp;&nbsp;.&nbsp; | &nbsp;&nbsp;.&nbsp; | &nbsp;&nbsp;.&nbsp; | &nbsp;&nbsp;4&nbsp; | &nbsp;&nbsp;.&nbsp; | &nbsp;&nbsp;.&nbsp; | &nbsp;&nbsp;.&nbsp; | &nbsp;&nbsp;.&nbsp; | &nbsp;&nbsp;.&nbsp; | &nbsp;&nbsp;.&nbsp; | &nbsp;&nbsp;.&nbsp; | &nbsp;&nbsp;.&nbsp; | &nbsp;&nbsp;.&nbsp; | &nbsp;&nbsp;.&nbsp; | &nbsp;&nbsp;.&nbsp; | &nbsp;&nbsp;.&nbsp; | &nbsp;&nbsp;1&nbsp; | &nbsp;&nbsp;.&nbsp; | &nbsp;&nbsp;5&nbsp; | &nbsp;&nbsp;&nbsp;din_rail_clip.stl |
| &nbsp;&nbsp;.&nbsp; | &nbsp;&nbsp;.&nbsp; | &nbsp;&nbsp;.&nbsp; | &nbsp;&nbsp;.&nbsp; | &nbsp;&nbsp;.&nbsp; | &nbsp;&nbsp;.&nbsp; | &nbsp;&nbsp;.&nbsp; | &nbsp;&nbsp;.&nbsp; | &nbsp;&nbsp;.&nbsp; | &nbsp;&nbsp;.&nbsp; | &nbsp;&nbsp;.&nbsp; | &nbsp;&nbsp;.&nbsp; | &nbsp;&nbsp;.&nbsp; | &nbsp;&nbsp;.&nbsp; | &nbsp;&nbsp;.&nbsp; | &nbsp;&nbsp;.&nbsp; | &nbsp;&nbsp;.&nbsp; | &nbsp;&nbsp;1&nbsp; | &nbsp;&nbsp;.&nbsp; | &nbsp;&nbsp;1&nbsp; | &nbsp;&nbsp;&nbsp;helping_hands_mount.stl |
| &nbsp;&nbsp;1&nbsp; | &nbsp;&nbsp;.&nbsp; | &nbsp;&nbsp;.&nbsp; | &nbsp;&nbsp;.&nbsp; | &nbsp;&nbsp;.&nbsp; | &nbsp;&nbsp;.&nbsp; | &nbsp;&nbsp;.&nbsp; | &nbsp;&nbsp;.&nbsp; | &nbsp;&nbsp;.&nbsp; | &nbsp;&nbsp;.&nbsp; | &nbsp;&nbsp;.&nbsp; | &nbsp;&nbsp;.&nbsp; | &nbsp;&nbsp;.&nbsp; | &nbsp;&nbsp;.&nbsp; | &nbsp;&nbsp;.&nbsp; | &nbsp;&nbsp;.&nbsp; | &nbsp;&nbsp;.&nbsp; | &nbsp;&nbsp;.&nbsp; | &nbsp;&nbsp;.&nbsp; | &nbsp;&nbsp;1&nbsp; | &nbsp;&nbsp;&nbsp;prop.stl |
| &nbsp;&nbsp;.&nbsp; | &nbsp;&nbsp;.&nbsp; | &nbsp;&nbsp;.&nbsp; | &nbsp;&nbsp;.&nbsp; | &nbsp;&nbsp;.&nbsp; | &nbsp;&nbsp;.&nbsp; | &nbsp;&nbsp;1&nbsp; | &nbsp;&nbsp;.&nbsp; | &nbsp;&nbsp;.&nbsp; | &nbsp;&nbsp;.&nbsp; | &nbsp;&nbsp;.&nbsp; | &nbsp;&nbsp;.&nbsp; | &nbsp;&nbsp;.&nbsp; | &nbsp;&nbsp;.&nbsp; | &nbsp;&nbsp;.&nbsp; | &nbsp;&nbsp;.&nbsp; | &nbsp;&nbsp;.&nbsp; | &nbsp;&nbsp;.&nbsp; | &nbsp;&nbsp;.&nbsp; | &nbsp;&nbsp;1&nbsp; | &nbsp;&nbsp;&nbsp;raspberry_pi_mounting_plate.stl |
| &nbsp;&nbsp;.&nbsp; | &nbsp;&nbsp;.&nbsp; | &nbsp;&nbsp;.&nbsp; | &nbsp;&nbsp;.&nbsp; | &nbsp;&nbsp;.&nbsp; | &nbsp;&nbsp;.&nbsp; | &nbsp;&nbsp;.&nbsp; | &nbsp;&nbsp;.&nbsp; | &nbsp;&nbsp;1&nbsp; | &nbsp;&nbsp;1&nbsp; | &nbsp;&nbsp;.&nbsp; | &nbsp;&nbsp;.&nbsp; | &nbsp;&nbsp;.&nbsp; | &nbsp;&nbsp;.&nbsp; | &nbsp;&nbsp;.&nbsp; | &nbsp;&nbsp;.&nbsp; | &nbsp;&nbsp;.&nbsp; | &nbsp;&nbsp;.&nbsp; | &nbsp;&nbsp;.&nbsp; | &nbsp;&nbsp;2&nbsp; | &nbsp;&nbsp;&nbsp;small_breadboard_holder.stl |

[Top](#TOP)

---

## Prop Assembly
### Vitamins
|Qty|Description|
|--:|:---|
|2|  3M Dual lock velcro 6mm long|
|2| 1 inch sq rubber foot|

### 3D Printed parts

| 1 x prop.stl |
|--|
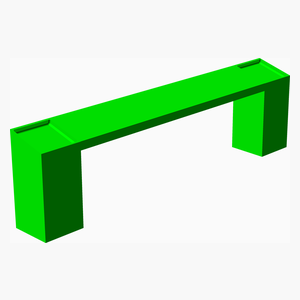
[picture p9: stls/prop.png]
prop.stl
|  

### Assembly instructions
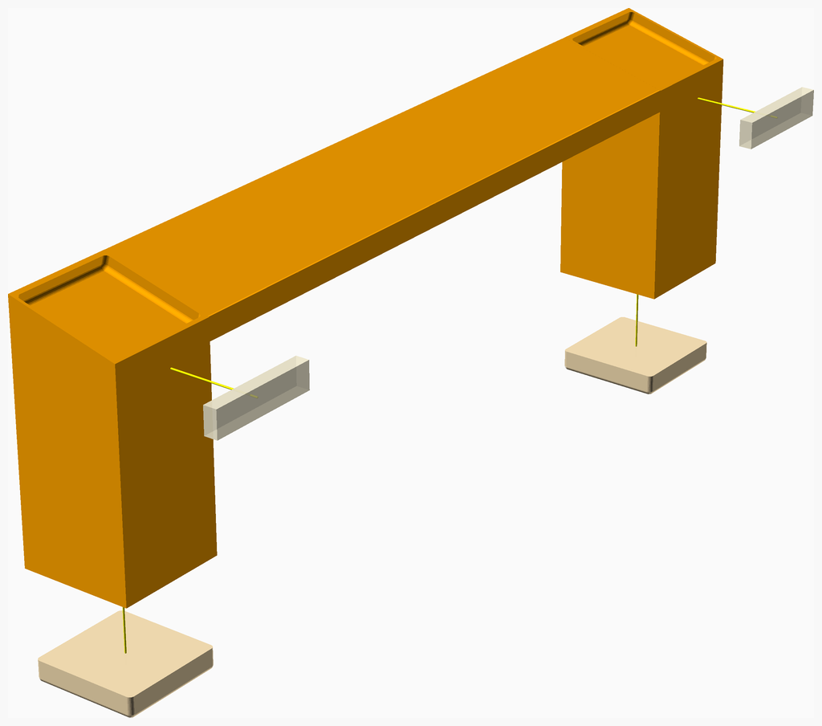
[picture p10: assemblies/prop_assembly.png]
prop_assembly


1. 3D print prop. [See Print Settings](#PRINT_SETTINGS)
2. Using scissors, cut 2 ea 6mm x 1in strip of 3M dual lock velcro.
3. Remove adhesive backing from dual lock strips and attach to prop as indicated.
4. Remove adhesive backing from the 2 each rubber feet and attach to the bottom of the prop.

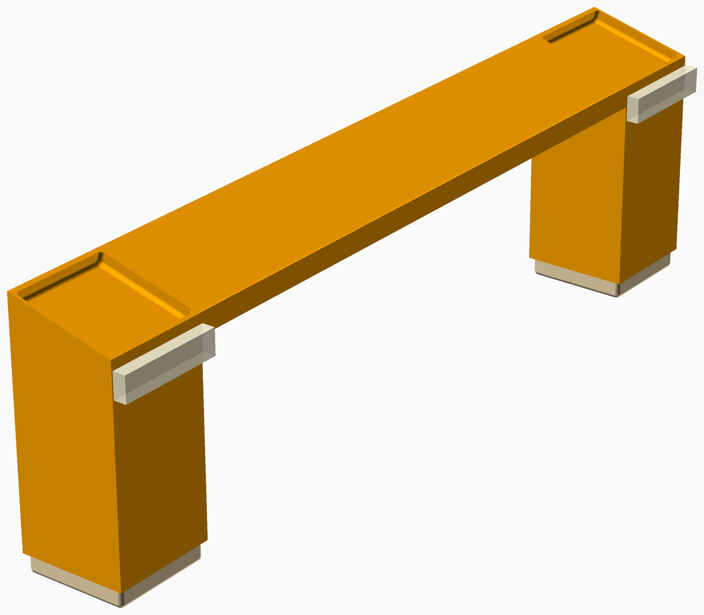
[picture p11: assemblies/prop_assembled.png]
prop_assembled


[Top](#TOP)

---

## Power Strip Assembly
### Vitamins
|Qty|Description|
|--:|:---|
|2|  3M Dual lock velcro 85mm long|
|1|  Super Danny 6 outlet Power Strip|

### Assembly instructions
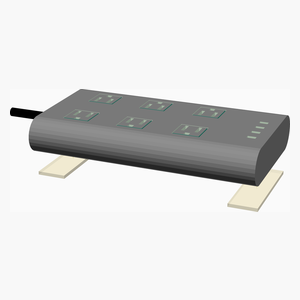
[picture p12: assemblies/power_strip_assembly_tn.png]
power_strip_assembly


1. Using scissors, cut 2 each 1in x 85MM dual lock velcro.
2. Remove backing from dual lock strips and attach to the bottom of the power strip as indicated.

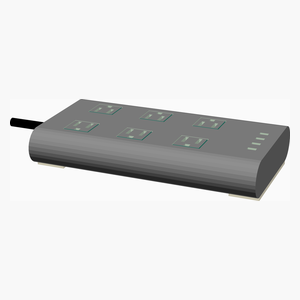
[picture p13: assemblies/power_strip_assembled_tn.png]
power_strip_assembled


[Top](#TOP)

---

## Tray Assembly
### Vitamins
|Qty|Description|
|--:|:---|
|2| Screw M3 cap x 12mm|
|2| Washer  M3 x 7mm x 0.5mm|

### Assembly instructions
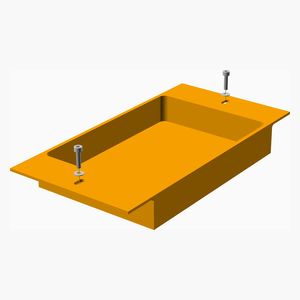
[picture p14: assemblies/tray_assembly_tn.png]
tray_assembly


1. Insert 2 ea. M3 x 12MM screws through two M3 flat washers.
2. Insert screw/washer assy through the front tray slots.
3. Secure tray to top frame assy. 

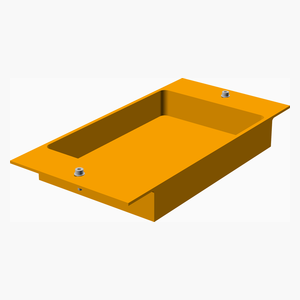
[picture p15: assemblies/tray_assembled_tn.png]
tray_assembled


[Top](#TOP)

---

## 4 x Corner Lamp Holder Assembly
### Vitamins
|Qty|Description|
|--:|:---|
|12| Screw M3 cap x 12mm|
|4| Screw M3 cap x 8mm|

### Assembly instructions
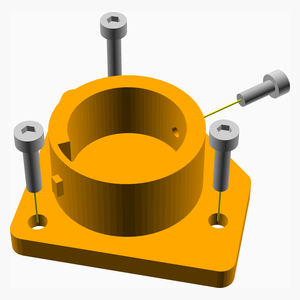
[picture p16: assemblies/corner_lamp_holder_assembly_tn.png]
corner_lamp_holder_assembly


1. 3D print 4 each lamp holder corner prieces. [See Print Settings](#PRINT_SETTINGS)
2. Using a 3mm x .5mm hole tap, tap the back horizontal hole for the 8mm M3 screw. This screw will be used to secure the lamp in place.
3. Screw in 8mm screw a few turns.
4. When the frame assembly is assembled, use the remaining 3 12MM M3 screws to secure to frame corners.

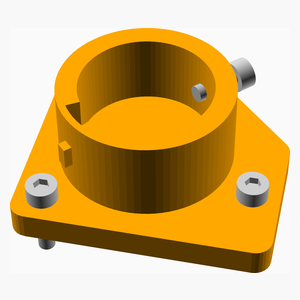
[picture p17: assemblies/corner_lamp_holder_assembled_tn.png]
corner_lamp_holder_assembled


[Top](#TOP)

---

## 4 x Din Rail Clip Assembly
### Vitamins
|Qty|Description|
|--:|:---|
|8| 3MM threaded rivet insert|

### 3D Printed parts

| 4 x din_rail_clip.stl |
|--|
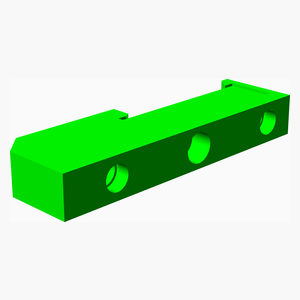
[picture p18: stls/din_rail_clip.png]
din_rail_clip.stl
|  

### Assembly instructions
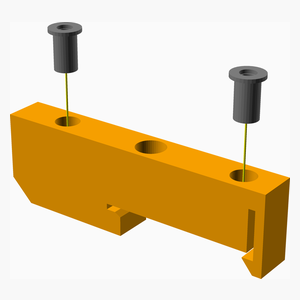
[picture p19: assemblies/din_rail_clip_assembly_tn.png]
din_rail_clip_assembly


1. 3D print 4 each din rail clips. [See Print Settings](#PRINT_SETTINGS)
2. Using a threaded insert rivet gun, insert the rivets as indicated.
3. Using an M3 tap, tap the small center hole.  This is optional and is be used to provide additional security of the din clip to the din rail.

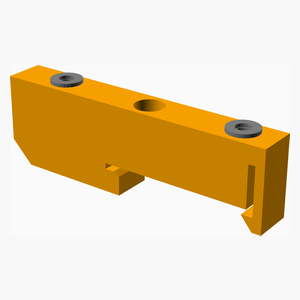
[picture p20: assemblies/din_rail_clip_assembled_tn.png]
din_rail_clip_assembled


[Top](#TOP)

---

## 4 x Back Spin Plate Assembly
### Vitamins
|Qty|Description|
|--:|:---|
|8| 3MM threaded rivet insert|

### 3D Printed parts

| 4 x back_spin_plate.stl |
|--|
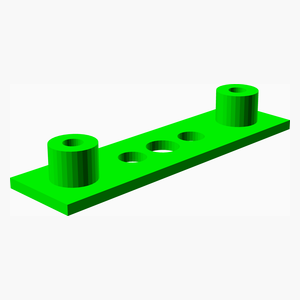
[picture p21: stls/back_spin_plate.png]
back_spin_plate.stl
|  

### Assembly instructions
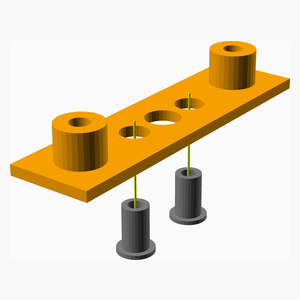
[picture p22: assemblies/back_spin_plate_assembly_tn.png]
back_spin_plate_assembly


1. 3D print 4 each back spin plates. [See Print Settings](#PRINT_SETTINGS)
2. Using a threaded insert rivet gun, insert the rivets as indicated.

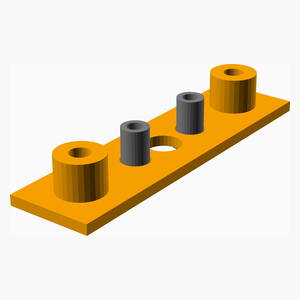
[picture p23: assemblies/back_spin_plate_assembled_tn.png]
back_spin_plate_assembled


[Top](#TOP)

---

## Raspberry Pi Mounting Plate Portrait Assembly
### Vitamins
|Qty|Description|
|--:|:---|
|1| Screw M3 cap x 16mm|
|1| Micro SD card|
|4| 3MM threaded rivet insert|
|1| Raspberry Pi 3|
|2| Screw M3 cap x 12mm|
|6| Screw M3 cap x 8mm|

### 3D Printed parts

| 1 x raspberry_pi_mounting_plate.stl |
|--|
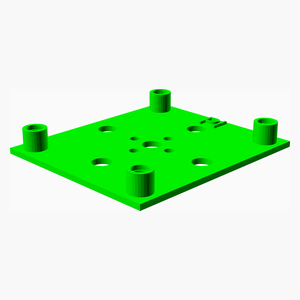
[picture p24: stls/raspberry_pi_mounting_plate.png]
raspberry_pi_mounting_plate.stl
|  

### Sub-assemblies

| 1 x back_spin_plate_assembly | 1 x din_rail_clip_assembly |
|--|--|
| back_spin_plate_assembled | din_rail_clip_assembled 

### Assembly instructions
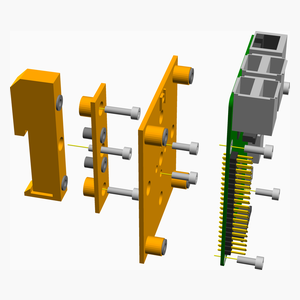
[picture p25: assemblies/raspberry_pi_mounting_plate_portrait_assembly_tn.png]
raspberry_pi_mounting_plate_portrait_assembly


1. 3D print 1 each raspberry pi mounting plate. [See Print Settings](#PRINT_SETTINGS)
2. Using a threaded insert rivet gun, insert the 4 rivets as indicated.
3. Attach Raspberry PI, backspin plate assy, and din rail clip assy together with screws.
4. 4 8MM screws secure the Raspberry pi to the mounting plate.
5. 2 8MM screw secure the raspbery pi mounting plate to the spin plate.
6. 2 12MM screws secure the spin plate to the din rail clip.
7. 1 16MM screw is optional and is used for additional security of the din rail clip to the din rail.

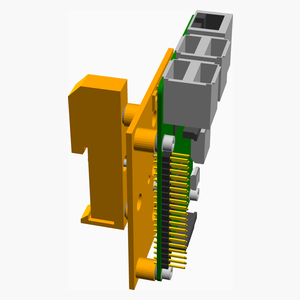
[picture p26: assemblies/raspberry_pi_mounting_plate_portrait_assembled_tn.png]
raspberry_pi_mounting_plate_portrait_assembled


[Top](#TOP)

---

## Arduino Uno Mounting Plate Portrait Assembly
### Vitamins
|Qty|Description|
|--:|:---|
|1| Screw M3 cap x 16mm|
|2| Screw M3 cap x 12mm|
|4| 3MM threaded rivet insert|
|1| Arduino Uno R3|
|6| Screw M3 cap x 8mm|

### 3D Printed parts

| 1 x arduino_uno_mounting_plate.stl |
|--|
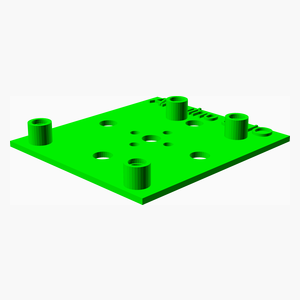
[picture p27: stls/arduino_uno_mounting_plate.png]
arduino_uno_mounting_plate.stl
|  

### Sub-assemblies

| 1 x back_spin_plate_assembly | 1 x din_rail_clip_assembly |
|--|--|
| back_spin_plate_assembled | din_rail_clip_assembled 

### Assembly instructions
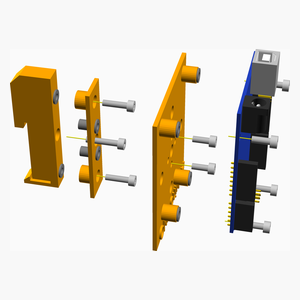
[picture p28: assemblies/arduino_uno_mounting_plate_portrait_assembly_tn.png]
arduino_uno_mounting_plate_portrait_assembly


1. 3D print 1 each Arduino Uno mounting plate. [See Print Settings](#PRINT_SETTINGS)
2. Using a threaded insert rivet gun, insert the 4 rivets as indicated.
3. Attach Arduino Uno, backspin plate assy, and din rail clip assy together with screws.
4. 4 8MM screws secure the Arduino Uno to the mounting plate.
5. 2 8MM screw secure the Arduino Uno mounting plate to the spin plate.
6. 2 12MM screws secure the spin plate to the din rail clip.
7. 1 16MM screw is optional and is used for additional security of the din rail clip to the din rail.

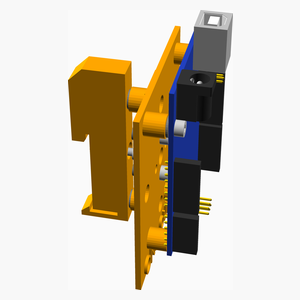
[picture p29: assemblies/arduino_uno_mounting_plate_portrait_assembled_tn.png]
arduino_uno_mounting_plate_portrait_assembled


[Top](#TOP)

---

## Small Breadboard Portrait Assembly
### Vitamins
|Qty|Description|
|--:|:---|
|1| Screw M3 cap x 16mm|
|1| Small Breadboard|
|1| Screw M3 cap x 5mm|
|2| Screw M3 cap x 12mm|
|2| Screw M3 cap x 8mm|

### 3D Printed parts

| 1 x small_breadboard_holder.stl |
|--|
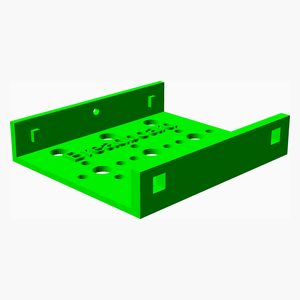
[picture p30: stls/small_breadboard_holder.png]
small_breadboard_holder.stl
|  

### Sub-assemblies

| 1 x back_spin_plate_assembly | 1 x din_rail_clip_assembly |
|--|--|
| back_spin_plate_assembled | din_rail_clip_assembled 

### Assembly instructions
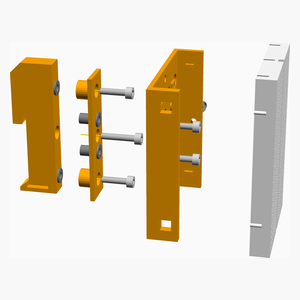
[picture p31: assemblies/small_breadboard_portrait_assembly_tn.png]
small_breadboard_portrait_assembly


1. 3D print 1 each small breadboard holder. [See Print Settings](#PRINT_SETTINGS)
2. Using a 3mm tap, tap the small horizontal hole located on the side of the breadboard holder.
3. 1 5MM screw secures the breadboard to the holder from the side.
4. 2 8MM screws secure the breadboard holder to the spin plate.
5. 2 12MM screws secure the spin plate to the din rail clip.
6. 1 16MM screw is optional and is used for additional security of the din rail clip to the din rail.

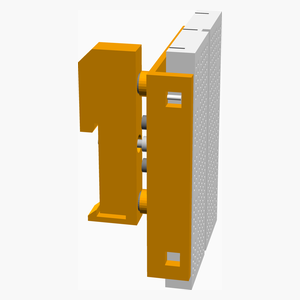
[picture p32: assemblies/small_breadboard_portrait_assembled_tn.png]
small_breadboard_portrait_assembled


[Top](#TOP)

---

## Small Breadboard Landscape Assembly
### Vitamins
|Qty|Description|
|--:|:---|
|1| Screw M3 cap x 16mm|
|1| Small Breadboard|
|1| Screw M3 cap x 5mm|
|2| Screw M3 cap x 12mm|
|2| Screw M3 cap x 8mm|

### 3D Printed parts

| 1 x small_breadboard_holder.stl |
|--|
| small_breadboard_holder.stl 

### Sub-assemblies

| 1 x back_spin_plate_assembly | 1 x din_rail_clip_assembly |
|--|--|
| back_spin_plate_assembled | din_rail_clip_assembled 

### Assembly instructions
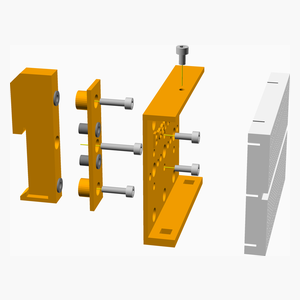
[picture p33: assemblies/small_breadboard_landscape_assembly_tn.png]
small_breadboard_landscape_assembly


1. 3D print 1 each small breadboard holder. [See Print Settings](#PRINT_SETTINGS)
2. Using a 3mm tap, tap the small horizontal hole located on the side of the breadboard holder.
3. 1 5MM screw secures the breadboard to the holder from the side.
4. 2 8MM screws secure the breadboard holder to the spin plate.
5. 2 12MM screws secure the spin plate to the din rail clip.
6. 1 16MM screw is optional and is used for additional security of the din rail clip to the din rail.

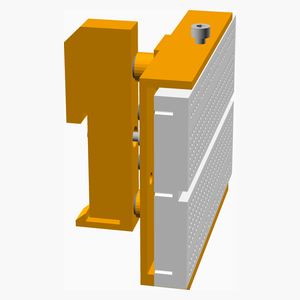
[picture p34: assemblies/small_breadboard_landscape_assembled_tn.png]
small_breadboard_landscape_assembled


[Top](#TOP)

---

## Carry Handle Assembly
### Vitamins
|Qty|Description|
|--:|:---|
|2| Screw M3 cap x 16mm|
|2| Washer  M3 x 7mm x 0.5mm|

### 3D Printed parts

| 1 x carry_handle.stl |
|--|
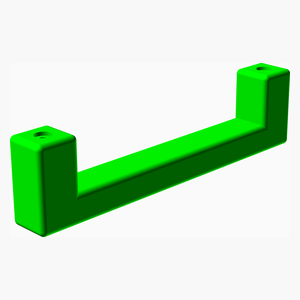
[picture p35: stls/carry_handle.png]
carry_handle.stl
|  

### Assembly instructions
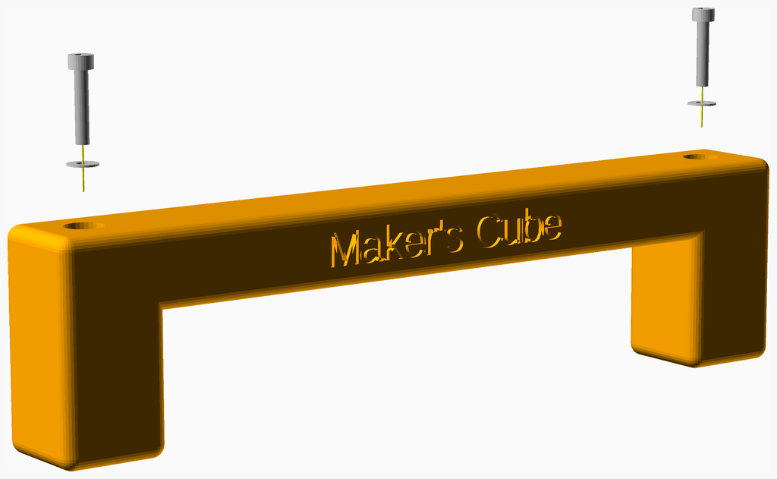
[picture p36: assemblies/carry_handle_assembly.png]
carry_handle_assembly


1. 3D print 1 each carry handle. [See Print Settings](#PRINT_SETTINGS)
2. Insert 2 each 16MM M3 screws into 2 each M3 washers.
3. Once frame assembly is assembled, attach carry hadndle to top of frame as indicated.  

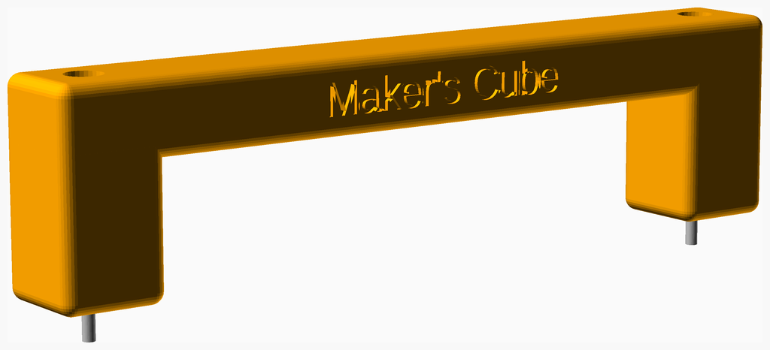
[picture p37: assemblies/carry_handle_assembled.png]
carry_handle_assembled


[Top](#TOP)

---

## Din Rail Assembly
### Vitamins
|Qty|Description|
|--:|:---|
|14| Screw M3 cap x 8mm|
|7| 35MM Din Rail 200 MM long|
|14| Washer  M3 x 7mm x 0.5mm|

### Assembly instructions
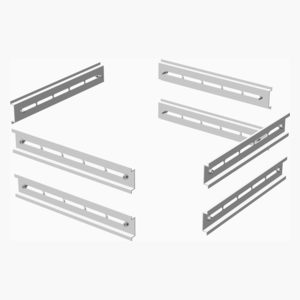
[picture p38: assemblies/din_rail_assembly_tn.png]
din_rail_assembly


1. Use M3 8MM screws and M3 washers to attach the din rail to the outer frame assembly.  
2. Position the din rail in any position which works best for your project need. 

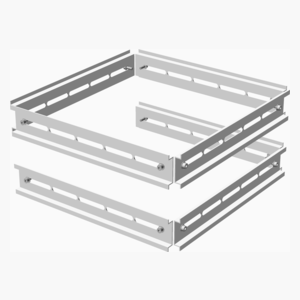
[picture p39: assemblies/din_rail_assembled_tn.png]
din_rail_assembled


[Top](#TOP)

---

## 4 x Corner Tube Top Assembly
### Vitamins
|Qty|Description|
|--:|:---|
|4| 3MM threaded rivet insert|

### Assembly instructions
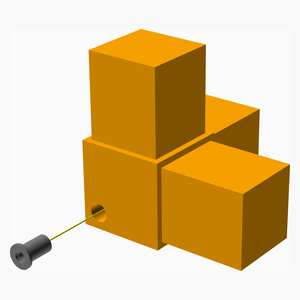
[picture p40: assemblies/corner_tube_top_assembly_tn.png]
corner_tube_top_assembly


1. 3D print 4 each corner tube connector tops . [See Print Settings](#PRINT_SETTINGS)
2. Using a threaded insert rivet gun, insert the rivets as indicated.

corner_tube_top_assembled

[Top](#TOP)

---

## Frame Bottom Assembly
### Vitamins
|Qty|Description|
|--:|:---|
|4| 1IN Aluminum Square Tube 149.2 MM long|
|20| 3MM threaded rivet insert|

### Assembly instructions
frame_bottom_assembly

1. Using a drill and a 5MM drill bit. Drill 5 each holes in each of the 4 rails (20 total). Drill pattern is below.  
2. Insert rivets using rivet gun.  Do NOT insert the end rivets until the corner connectors are installed. 
 <br>

frame_bottom_assembled

[Top](#TOP)

---

## Frame Middle Assembly
### Vitamins
|Qty|Description|
|--:|:---|
|4| 1IN Aluminum Square Tube 149.2 MM long|
|40| 3MM threaded rivet insert|

### Assembly instructions
frame_middle_assembly

1. Using a drill and a 5MM drill bit. Drill 10 each holes in each of the 4 rails (40 total). Drill pattern is below.  
2. Insert rivets using rivet gun.  Do NOT insert the end rivets until the corner connectors are installed. 
 <br>

frame_middle_assembled

[Top](#TOP)

---

## Frame Top Assembly
### Vitamins
|Qty|Description|
|--:|:---|
|4| 1IN Aluminum Square Tube 149.2 MM long|
|40| 3MM threaded rivet insert|

### Assembly instructions
frame_top_assembly

1. Using a drill and a 5MM drill bit. Drill 10 each holes in each of the 4 rails (40 total). Drill pattern is below.  
2. Insert rivets using rivet gun.  Do NOT insert the end rivets until the corner connectors are installed. 
 <br>

frame_top_assembled

[Top](#TOP)

---

## Frame Assembly
### 3D Printed parts

| 4 x corner_tube_connector_bottom.stl |
|--|
| corner_tube_connector_bottom.stl 

### Sub-assemblies

| 4 x corner_tube_top_assembly | 1 x frame_bottom_assembly | 1 x frame_middle_assembly |
|--|--|--|
| corner_tube_top_assembled | frame_bottom_assembled | frame_middle_assembled 

| 1 x frame_top_assembly |
|--|
| frame_top_assembled 

### Assembly instructions
frame_assembly

frame_assembled

[Top](#TOP)

---

## Helping Hands Assembly
### Vitamins
|Qty|Description|
|--:|:---|
|2| 3MM Armature wire - 5 inches long|
|2| Alligator Clip|
|1| Screw M3 cap x 16mm|
|2| Screw M3 cap x 12mm|
|6| Screw M3 cap x 8mm|

### 3D Printed parts

| 2 x armature_union.stl | 1 x din_rail_clip.stl | 1 x helping_hands_mount.stl |
|--|--|--|
| armature_union.stl | din_rail_clip.stl | helping_hands_mount.stl 

### Assembly instructions
helping_hands_assembly

1. 3D print 2 each armature union, din rail clip, and helping hands mount [See Print Settings](#PRINT_SETTINGS)
2. Using a 3MM tap, tap the 4 holes of the armature unions.  
3. Using a 3MM tap, tap the 2 holes located on the face of the helping hands mount. 
4. Cut 2 each 5 inch sections of the 3MM armature wire.
5. insert one side of the armature wire into the armature union and an alligator clip into the other end of the armature union and secure with the 8MM screws. 
6. Insert the other end of the 3MM armature wire into the helping hands mount and secure with a 8MM M3 screw.
7. Use the 2 12MM M3 screws to secure the helping hands mount to the din rail clip. 

helping_hands_assembled

[Top](#TOP)

---

## Main Assembly
### Vitamins
|Qty|Description|
|--:|:---|
|2|  3M Dual lock velcro 149mm long|
|1| Magnifier Lamp Assembly|
|2|  3M Dual lock velcro 6mm long|
|4| 1 inch sq rubber foot|

### Sub-assemblies

| 1 x arduino_uno_mounting_plate_portrait_assembly | 1 x carry_handle_assembly | 4 x corner_lamp_holder_assembly |
|--|--|--|
| arduino_uno_mounting_plate_portrait_assembled | carry_handle_assembled | corner_lamp_holder_assembled 

| 1 x din_rail_assembly | 1 x frame_assembly | 1 x helping_hands_assembly |
|--|--|--|
| din_rail_assembled | frame_assembled | helping_hands_assembled 

| 1 x power_strip_assembly | 1 x prop_assembly | 1 x raspberry_pi_mounting_plate_portrait_assembly |
|--|--|--|
| power_strip_assembled | prop_assembled | raspberry_pi_mounting_plate_portrait_assembled 

| 1 x small_breadboard_landscape_assembly | 1 x small_breadboard_portrait_assembly | 1 x tray_assembly |
|--|--|--|
| small_breadboard_landscape_assembled | small_breadboard_portrait_assembled | tray_assembled 

### Assembly instructions
main_assembly

1. Cut 2 each 149mm sections of dual lock velcro.
2. Remove dual lock backing and stick to the front and back inner bottom frame assembly. The power supply will stick to these velcro strips. 
3. Attach 4 each rubber feet to the bottom 4 corners of the cube.
4. Cut 2 each 6mm sections of dual lock velcro.
5. Attach these small strips of velcro to the left inner frame where the prop will go when it is stored inside the cube. 
6. Insert LED magnifying lamp into one of the 4 corner posts.
7. Attach all other assemblies as indicated.

main_assembled

[Top](#TOP)
"# open-makers-cube"

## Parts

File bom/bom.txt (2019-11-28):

Vitamins:
                                              R         
 A                                            a         
 r                                            s         
 d                                            p         
 u                                            b         
 i                                            e         
 n                                            r         
 o                                            r         
                                              y         
 u                                                      
 n                                            p  S      
 o                                            i  m  S   
                                                 a  m   
 m                                            m  l  a   
 o                                            o  l  l   
 u                                            u     l   
 n                                            n  b      
 t                                            t  r  b   
 i        C                                   i  e  r   
 n        o                                   n  a  e   
 g        r                                   g  d  a   
    B     n  C                                   b  d   
 p  a     e  o                                p  o  b   
 l  c     r  r     D              H           l  a  o   
 a  k  C     n     i     F  F     e           a  r  a   
 t     a  l  e     n     r  r     l     P     t  d  r   
 e  s  r  a  r           a  a     p     o     e     d   
    p  r  m        r     m  m  F  i     w        l      
 p  i  y  p  t  D  a     e  e  r  n     e     p  a  p   
 o  n        u  i  i           a  g     r     o  n  o   
 r     h  h  b  n  l     b  m  m              r  d  r   
 t  p  a  o  e        F  o  i  e  h     s     t  s  t   
 r  l  n  l     r  c  r  t  d     a  M  t  P  r  c  r  T
 a  a  d  d  t  a  l  a  t  d  t  n  a  r  r  a  a  a  r
 i  t  l  e  o  i  i  m  o  l  o  d  i  i  o  i  p  i  a
 t  e  e  r  p  l  p  e  m  e  p  s  n  p  p  t  e  t  y
  |  |  |  |  |  |  |  |  |  |  |  | 2|  |  |  |  |  |  |  2  3M Dual lock velcro 149mm long
  |  |  |  |  |  |  |  |  |  |  |  | 2|  | 2|  |  |  |  |  4  3M Dual lock velcro 6mm long
  |  |  |  |  |  |  |  |  |  |  |  |  | 2|  |  |  |  |  |  2  3M Dual lock velcro 85mm long
  |  |  |  |  |  |  |  |  |  |  |  |  | 1|  |  |  |  |  |  1  Super Danny 6 outlet Power Strip
  |  |  |  |  |  |  |  |  |  |  |  | 4|  | 2|  |  |  |  |  6 1 inch sq rubber foot
  |  |  |  |  |  |  |  | 4| 4| 4|  |  |  |  |  |  |  |  | 12 1IN Aluminum Square Tube 149.2 MM long
  |  |  |  |  | 7|  |  |  |  |  |  |  |  |  |  |  |  |  |  7 35MM Din Rail 200 MM long
 4| 8|  |  | 4|  | 8|  |20|40|40|  |  |  |  | 4|  |  |  |128 3MM threaded rivet insert
  |  |  |  |  |  |  |  |  |  |  | 2|  |  |  |  |  |  |  |  2 Alligator Clip
  |  |  |  |  |  |  |  |  |  |  |  | 1|  |  |  |  |  |  |  1 Magnifier Lamp Assembly
  |  |  |  |  |  |  |  |  |  |  |  |  |  |  |  | 1| 1|  |  2 Small Breadboard
  |  |  |  |  |  |  |  |  |  |  |  |  |  |  | 1|  |  |  |  1 Micro SD card
  |  |  |  |  |  |  |  |  |  |  | 2|  |  |  |  |  |  |  |  2 3MM Armature wire - 5 inches long
 1|  |  |  |  |  |  |  |  |  |  |  |  |  |  |  |  |  |  |  1 Arduino Uno R3
  |  |  |  |  |  |  |  |  |  |  |  |  |  |  | 1|  |  |  |  1 Raspberry Pi 3
 2|  |  |12|  |  |  |  |  |  |  | 2|  |  |  | 2| 2| 2| 2| 24 Screw M3 cap x 12mm
 1|  | 2|  |  |  |  |  |  |  |  | 1|  |  |  | 1| 1| 1|  |  7 Screw M3 cap x 16mm
  |  |  |  |  |  |  |  |  |  |  |  |  |  |  |  | 1| 1|  |  2 Screw M3 cap x 5mm
 6|  |  | 4|  |14|  |  |  |  |  | 6|  |  |  | 6| 2| 2|  | 40 Screw M3 cap x 8mm
  |  | 2|  |  |14|  |  |  |  |  |  |  |  |  |  |  |  | 2| 18 Washer  M3 x 7mm x 0.5mm

Printed:
 1|  |  |  |  |  |  |  |  |  |  |  |  |  |  |  |  |  |  |  1 arduino_uno_mounting_plate.stl
  |  |  |  |  |  |  |  |  |  |  | 2|  |  |  |  |  |  |  |  2 armature_union.stl
  | 4|  |  |  |  |  |  |  |  |  |  |  |  |  |  |  |  |  |  4 back_spin_plate.stl
  |  | 1|  |  |  |  |  |  |  |  |  |  |  |  |  |  |  |  |  1 carry_handle.stl
  |  |  |  |  |  |  | 4|  |  |  |  |  |  |  |  |  |  |  |  4 corner_tube_connector_bottom.stl
  |  |  |  |  |  | 4|  |  |  |  | 1|  |  |  |  |  |  |  |  5 din_rail_clip.stl
  |  |  |  |  |  |  |  |  |  |  | 1|  |  |  |  |  |  |  |  1 helping_hands_mount.stl
  |  |  |  |  |  |  |  |  |  |  |  |  |  | 1|  |  |  |  |  1 prop.stl
  |  |  |  |  |  |  |  |  |  |  |  |  |  |  | 1|  |  |  |  1 raspberry_pi_mounting_plate.stl
  |  |  |  |  |  |  |  |  |  |  |  |  |  |  |  | 1| 1|  |  2 small_breadboard_holder.stl

Assemblies:
  1 arduino_uno_mounting_plate_portrait_assembly
  4 back_spin_plate_assemblies
  1 carry_handle_assembly
  4 corner_lamp_holder_assemblies
  4 corner_tube_top_assemblies
  1 din_rail_assembly
  4 din_rail_clip_assemblies
  1 frame_assembly
  1 frame_bottom_assembly
  1 frame_middle_assembly
  1 frame_top_assembly
  1 helping_hands_assembly
  1 main_assembly
  1 power_strip_assembly
  1 prop_assembly
  1 raspberry_pi_mounting_plate_portrait_assembly
  1 small_breadboard_landscape_assembly
  1 small_breadboard_portrait_assembly
  1 tray_assembly

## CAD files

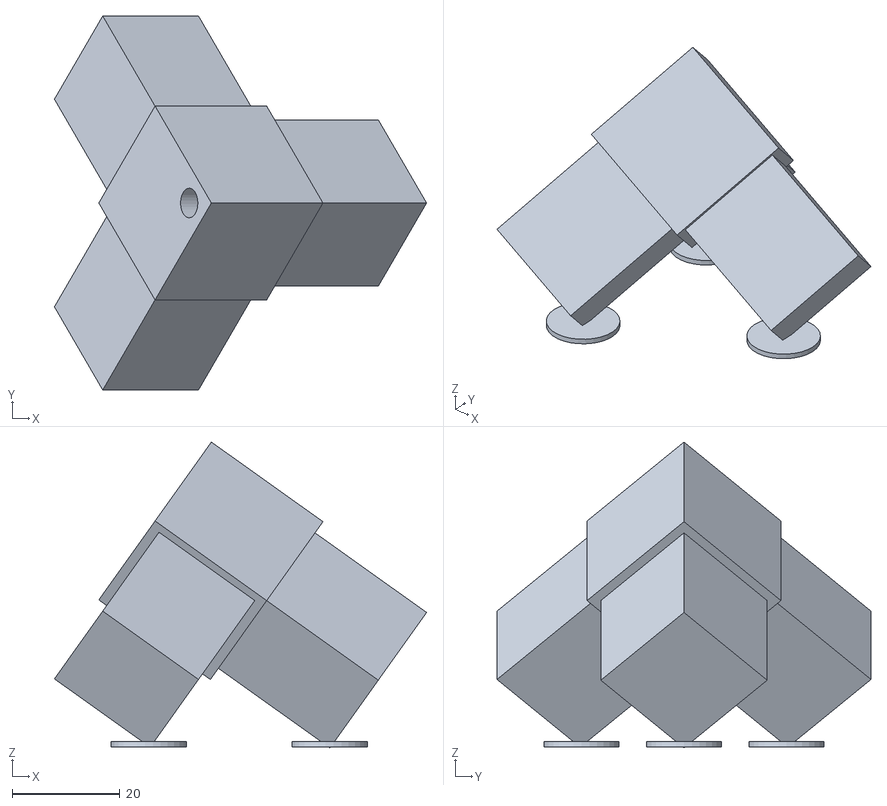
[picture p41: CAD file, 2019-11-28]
docs/corner_tube_connector_top_v2.stl
69.0 x 69.3 x 56.7

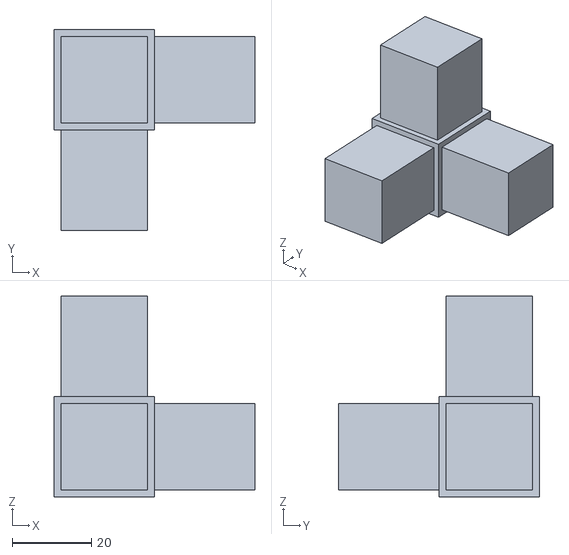
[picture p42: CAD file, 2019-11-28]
stls/corner_tube_connector_bottom.stl
50.8 x 50.8 x 50.8

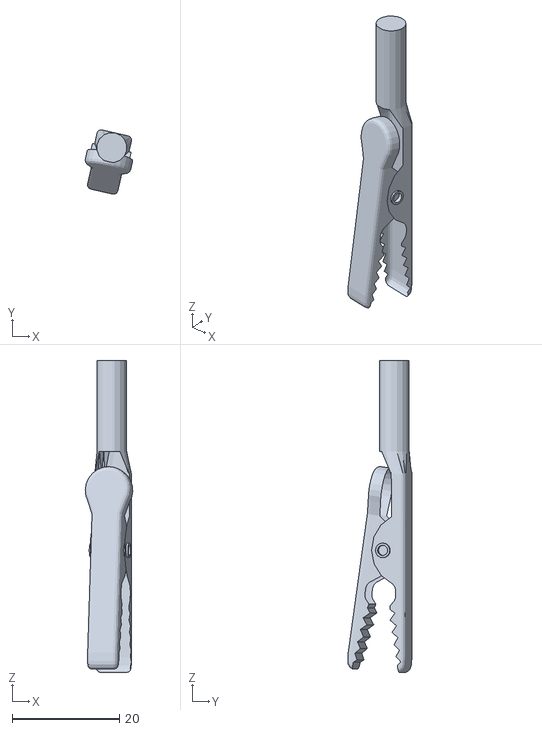
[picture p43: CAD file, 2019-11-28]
vitamins/alligator_clip.stl
8.87 x 12.0 x 58.2

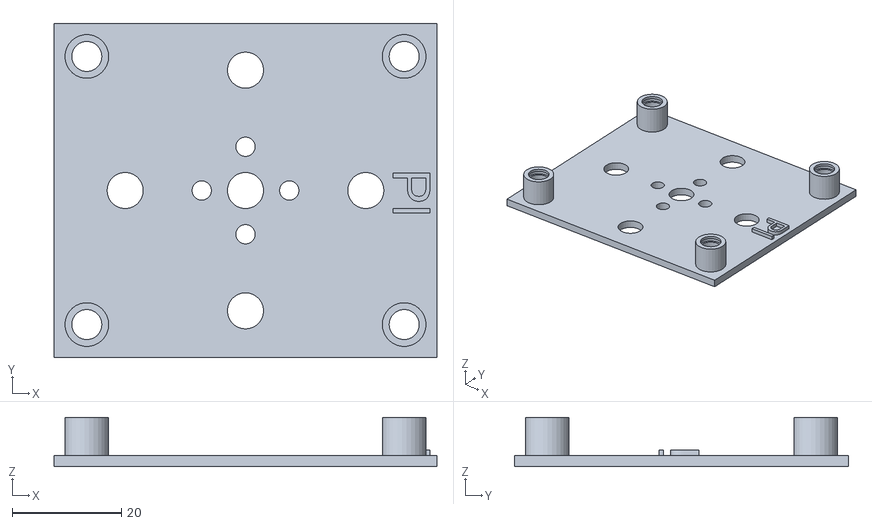
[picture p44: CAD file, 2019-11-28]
stls/raspberry_pi_mounting_plate.stl
70.0 x 61.0 x 9.00

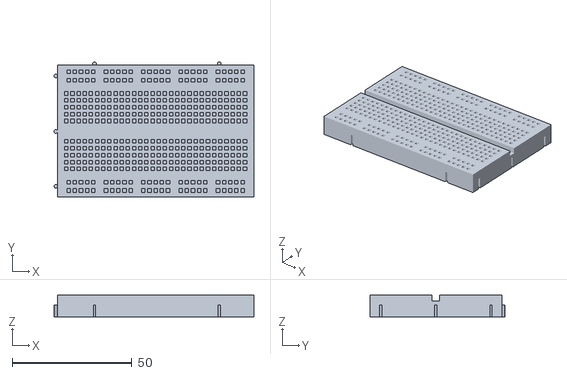
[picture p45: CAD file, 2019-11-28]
vitamins/small_breadboard.stl
83.4 x 56.4 x 9.00

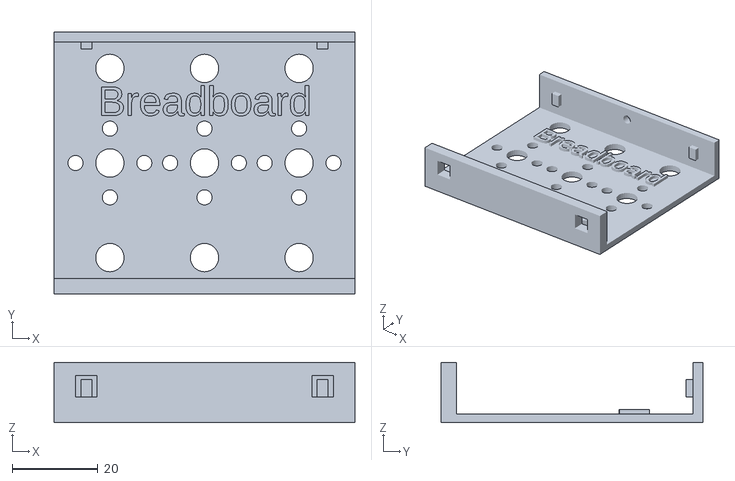
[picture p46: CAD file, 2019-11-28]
stls/small_breadboard_holder.stl
70.0 x 61.0 x 14.0

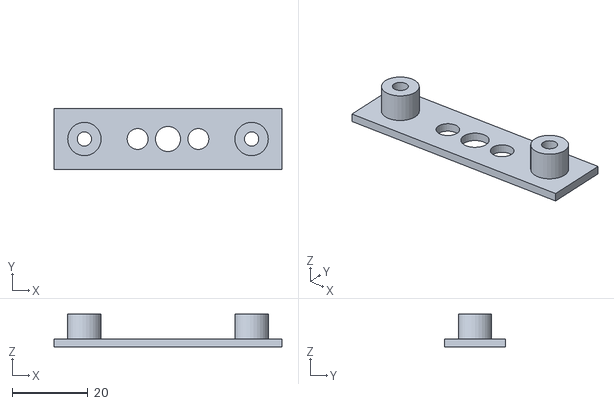
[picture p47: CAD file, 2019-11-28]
stls/back_spin_plate.stl
60.0 x 16.0 x 8.60

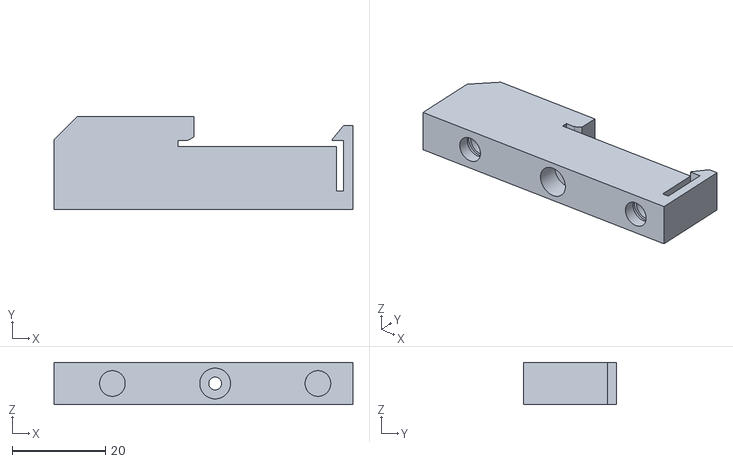
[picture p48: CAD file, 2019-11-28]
stls/din_rail_clip.stl
64.0 x 20.0 x 9.00

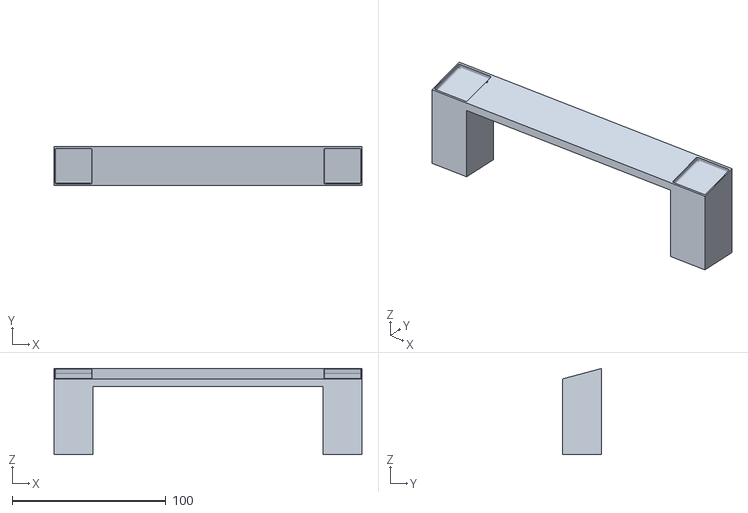
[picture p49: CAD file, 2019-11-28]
stls/prop.stl
200.0 x 25.4 x 55.9

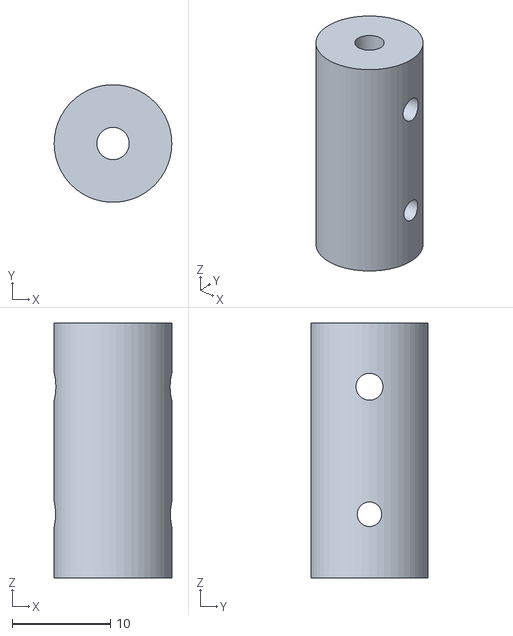
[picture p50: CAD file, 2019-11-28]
stls/armature_union.stl
12.0 x 12.0 x 26.0

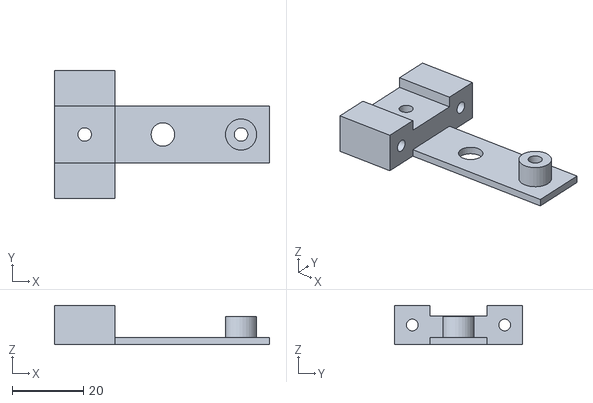
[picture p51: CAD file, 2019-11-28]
stls/helping_hands_mount.stl
60.5 x 36.0 x 11.0

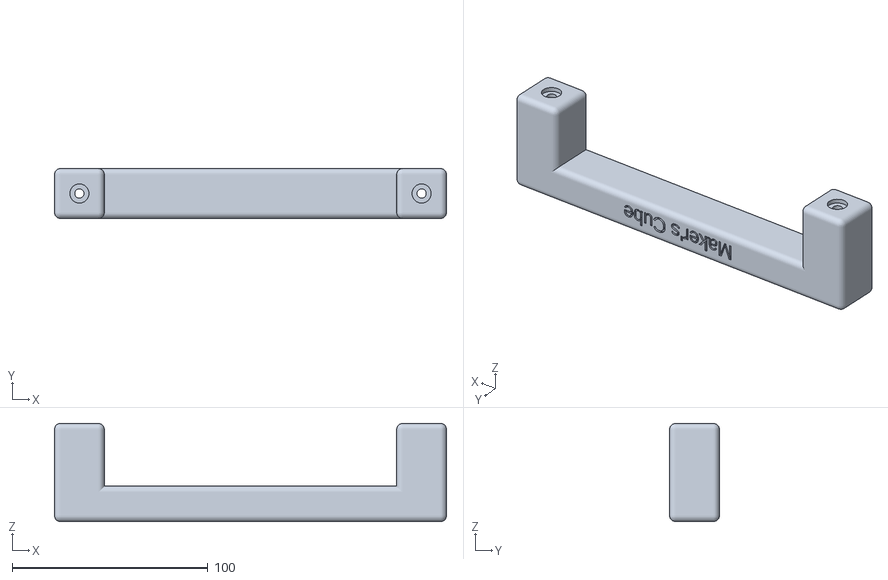
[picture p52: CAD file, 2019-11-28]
stls/carry_handle.stl
200.0 x 25.4 x 50.0

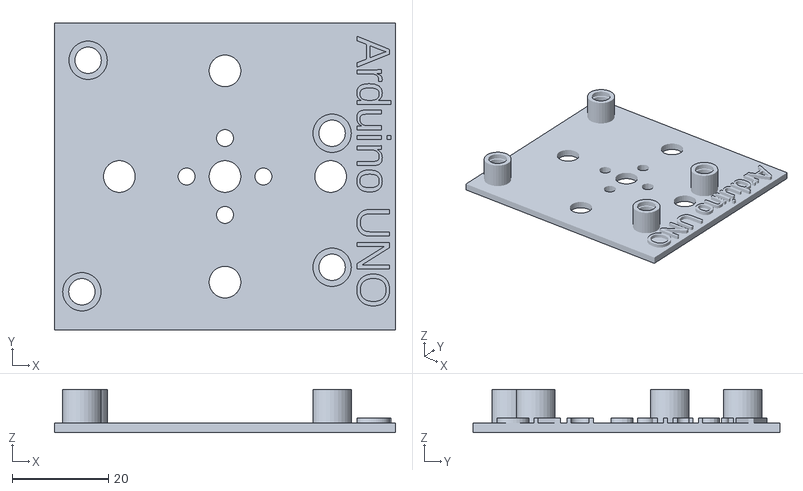
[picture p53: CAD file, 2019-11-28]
stls/arduino_uno_mounting_plate.stl
71.0 x 64.0 x 9.00

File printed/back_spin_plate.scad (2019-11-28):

//
// Open Makers Cube Copyright 2019 
// Chris Wilson
// cmsjwilson@gmail.com
//
// This file is part of Open Makers Cube Project.
//
// Open Makers Cube is free software: you can redistribute it and/or modify it under the terms of the
// GNU General Public License as published by the Free Software Foundation, either version 3 of
// the License, or (at your option) any later version.
//
// Open Makers Cube is distributed in the hope that it will be useful, but WITHOUT ANY WARRANTY;
// without even the implied warranty of MERCHANTABILITY or FITNESS FOR A PARTICULAR PURPOSE.
// See the GNU General Public License for more details.
//
// You should have received a copy of the GNU General Public License along with Open Makers Cube.
// If not, see <https://www.gnu.org/licenses/>.
//


include <NopSCADlib/lib.scad>   

// ============ Constants ===============
IN = 25.4;
MM = 1;
$fn = 30;

LARGE_HOLE_DIA = 6*MM;
RIVET_HOLE_DIA = 5*MM;



// center to center
LARGE_HOLE_CC = 22*MM;



body_dim = [60*MM, 16*MM, 2*MM];
post_dia = 8*MM;
post_ht  = 6*MM;
post_inner_dia = 3.4*MM;


// scaling for 3D printers

HOLE_SIZE_COEF = 1.1;

NONE   = 0;
TEVO   = 1;
ENDER3 = 2;

3DPRINTER_SCALE = [
    [1, 1, 1],    // NONE.  no rescaling
    [1, 1, 1], // TEVO
    [1, 1, 1]  // ENDER3
];

// ============ Renders ===============


//back_spin_plate_3d_print_ready(NONE);
//back_spin_plate_3d_print_ready(TEVO);
//back_spin_plate_3d_print_ready(ENDER3);

//back_spin_plate(countersink=true);



//back_spin_plate();
// ============ Modules ===============

module back_spin_plate_3d_print_ready(scale_factor = NONE){
    scale(3DPRINTER_SCALE[scale_factor])
    back_spin_plate(rivet_holes=true);

}

module back_spin_plate(rivet_holes=true, post_height=post_ht, countersink=true){
  stl("back_spin_plate");

  difference(){

    cube(body_dim);
    large_holes(countersink=countersink);
    if (rivet_holes)
     rivet_holes();
  }

  difference(){
   posts(post_height=post_height);
   large_holes(countersink=countersink);
  }




}

module back_spin_plate_helping_hands(rivet_holes=true, post_height=post_ht, countersink=true){
  //stl("back_spin_plate");

  difference(){

    cube(body_dim);
    large_holes(countersink=countersink);
    if (rivet_holes)
     rivet_holes();
  }

  difference(){
   posts(post_height=post_height);
   large_holes(countersink=countersink);
  }




}
module rivet_holes(){
    translate([(body_dim[0]/2) - 8*MM, body_dim[1]/2, -2])
       scale(HOLE_SIZE_COEF)
       cylinder(d=RIVET_HOLE_DIA, h=5*MM);

    translate([(body_dim[0]/2) + 8*MM, body_dim[1]/2, -2])
       scale(HOLE_SIZE_COEF)
       cylinder(d=RIVET_HOLE_DIA, h=5*MM);


}

module posts(post_height = post_ht){
    translate([body_dim[0]/2, body_dim[1]/2, 0])
    for (i = [-1:1]){
        
        // skip center post
        if (i != 0){

            difference(){

                union(){
                    translate([i*LARGE_HOLE_CC, 0, 2])
                    scale(HOLE_SIZE_COEF)
                        //cylinder(d=post_dia, h=post_ht);
                        cylinder(d=post_dia, h=post_height);
                }
                union(){
                    translate([i*LARGE_HOLE_CC, 0, 0])
                    scale(HOLE_SIZE_COEF)
                        cylinder(d=post_inner_dia, h=20*MM);
                }
            }// difference
        }// for i
    }

}


module large_holes(countersink=true){

    translate([body_dim[0]/2, body_dim[1]/2, 0])
    for (i = [-1:1]){


      // always make center hole
      if (i== 0){
       translate([i*LARGE_HOLE_CC, 0, -1])
        scale(HOLE_SIZE_COEF)
        cylinder(d=LARGE_HOLE_DIA, h=4*MM);
      }

      // outer holes are optional base on arg countersink
      if ((i == -1) && (countersink == true)){
       translate([i*LARGE_HOLE_CC, 0, -1])
        scale(HOLE_SIZE_COEF)
        cylinder(d=LARGE_HOLE_DIA, h=4*MM);
      }

      if ((i == 1) && (countersink == true)){
       translate([i*LARGE_HOLE_CC, 0, -1])
        scale(HOLE_SIZE_COEF)
        cylinder(d=LARGE_HOLE_DIA, h=4*MM);
      }
    }

}

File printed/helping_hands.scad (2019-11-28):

//
// Open Makers Cube Copyright 2019 
// Chris Wilson
// cmsjwilson@gmail.com
//
// This file is part of Open Makers Cube Project.
//
// Open Makers Cube is free software: you can redistribute it and/or modify it under the terms of the
// GNU General Public License as published by the Free Software Foundation, either version 3 of
// the License, or (at your option) any later version.
//
// Open Makers Cube is distributed in the hope that it will be useful, but WITHOUT ANY WARRANTY;
// without even the implied warranty of MERCHANTABILITY or FITNESS FOR A PARTICULAR PURPOSE.
// See the GNU General Public License for more details.
//
// You should have received a copy of the GNU General Public License along with Open Makers Cube.
// If not, see <https://www.gnu.org/licenses/>.
//


// BOSL Library 
include <bosl/constants.scad>
use <bosl/shapes.scad>
use <bosl/transforms.scad>
use <BOSL/wiring.scad>


// makers cube files
use<back_spin_plate.scad>
use<din_rail_clip.scad>
use<../vitamins/rivet.scad>
use <../vitamins/alligator_clip.scad>
use <../printed/armature_union.scad>


// https://github.com/nophead/NopSCADlib
// referenced from the OPENSCADPATH env variable
include <NopSCADlib/core.scad>  
include <NopSCADlib/vitamins/screws.scad>
include </dotSCAD/src/rounded_square.scad>;


 
// ============ Constants ===============
IN = 25.4;
MM = 1;
$fn = 30;


head_dim  = [17*MM, 36*MM, 11*MM ];

/*
 head  - top part holds armature wires
 bsp   - back spin plate arm. union in a back_spin_plate
*/

// armatrue
arm_hole_dia    = 3*MM;
arm_hole_c_to_c = 26*MM;

arm_clamp_hole_dia = 2.5*MM; // M3 screw to hole arm wire in place

// scaling for 3D printers

HOLE_SIZE_COEF = 1.1;

NONE   = 0;
TEVO   = 1;
ENDER3 = 2;

3DPRINTER_SCALE = [
    [1, 1, 1],    // NONE.  no rescaling
    [1, 1, 1], // TEVO
    [1, 1, 1]  // ENDER3
];

echo($vpr, $vpt);
// ============ Renders ===============

//helping_hands_mount_3d_print_ready(NONE);
//helping_hands_mount_3d_print_ready(TEVO);
//helping_hands_mount_3d_print_ready(ENDER3);

// entire assembly 
//$explode = 1;
helping_hands_assy();


// ============ Modules ===============

module helping_hands_mount_3d_print_ready(scale_factor=NONE){
    scale(3DPRINTER_SCALE[scale_factor])
      helping_hands_mount();
}

module helping_hands_mount(){
 //vitamin(" : helping hands mount");
 color(pp1_colour) stl("helping_hands_mount");// generates stl 

  color("orange")
  union(){

    difference(){
      cube(head_dim, center=true);
      arm_holes();
      clamp_holes();
      head_notch();
      head_center_hole();
    }

    difference(){
      tail();
      head_center_hole();
      xmove(22*MM * 2) head_center_hole();
    }
  }



}

module head_notch(){
  zmove(6.5*MM)
   cube([head_dim[0] + 2*MM, 16*MM, 8*MM], center=true);
}
 
module tail(){
translate([-8*MM, -8*MM, -head_dim[2]/2])
   back_spin_plate_helping_hands(rivet_holes = false, countersink=false, post_height=5.4*MM);
}

module head_center_hole(){
  zcyl(d=3.8*MM, h=head_dim[2] + 2*MM);
}

// using BSOL library
module arm_holes(){
  yspread(arm_hole_c_to_c, n=2) 
  scale(HOLE_SIZE_COEF)
  xcyl(l=head_dim[0] + 1*MM, d=arm_hole_dia); 
}

// using BSOL library
module clamp_holes(){
  yspread(arm_hole_c_to_c, n=2) zmove(-head_dim[2]/2 + 2.5*MM) 
  scale(HOLE_SIZE_COEF)
  zcyl(l=(head_dim[2])/2 + 1*MM, d=arm_clamp_hole_dia); 
}

module armature_wire(){
     vitamin("armature_wire() : 3MM Armature wire - 5 inches long");
    // 3mm armature wire
    union(){
        zrot(90)
        color("white") wiring([
            [0,-30,30], [0,-30,50], [0,0,50], [0,0,10]
            ], 
        fillet=10, wires=1, wirediam=3);
    }

}

module armature_arm(){
       union(){

            // stl for 'printed' parts
            color(pp1_colour) stl("armature_union");// generates stl 
            //color(pp1_colour) armature_union_stl();
            color("orange") armature_union(); 
            //%armature_union(); 

 
            // 2 securing screws
            xmove(10)
            union(){
                zmove(13)
                xmove(-20) zrot(-90) xrot(90)
                screw(M3_cap_screw, 8);

                xmove(-20) zrot(-90) xrot(90)
                screw(M3_cap_screw, 8);
            }



           //$explode=1;
            explode(d=20, offset=[0,0,10])
            armature_wire();

            color("silver") 
            explode(d=[0,0,-30])
            alligator_clip();

       }

}

module screw_assy(){
  // screws
  color("silver")

  xrot(180)
  zmove(10)
  union(){
    // 8MM hold armature wire to mounting plate
    zmove(-8)
    yspread(arm_hole_c_to_c) screw(M3_cap_screw, 8);

    // 12MM hold mounting plate to din rail clip 
    zmove(-12)
    xmove(22)
    xspread(22*2) screw(M3_cap_screw, 12);


    // 16MM secure din rail clip to din rail
    //zmove(-64)
    zmove(-18)
    xmove(22)
    screw(M3_cap_screw, 16);


  }

}

module helping_hands_assy(){
    xmove(23)
    zmove(30)
    yrot(90)
    screw_assy();
    zmove(30)
    xmove(30)
    xrot(180)
    yrot(90)
    zrot(180)
    helping_hands_mount();

    yspread(26) armature_arm();
    
    zmove(43)
    ymove(4.5)
    xmove(33)
    yrot(90)
    xrot(90)
    din_rail_clip(true);

}

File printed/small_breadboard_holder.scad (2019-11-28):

//
// Open Makers Cube Copyright 2019 
// Chris Wilson
// cmsjwilson@gmail.com
//
// This file is part of Open Makers Cube Project.
//
// Open Makers Cube is free software: you can redistribute it and/or modify it under the terms of the
// GNU General Public License as published by the Free Software Foundation, either version 3 of
// the License, or (at your option) any later version.
//
// Open Makers Cube is distributed in the hope that it will be useful, but WITHOUT ANY WARRANTY;
// without even the implied warranty of MERCHANTABILITY or FITNESS FOR A PARTICULAR PURPOSE.
// See the GNU General Public License for more details.
//
// You should have received a copy of the GNU General Public License along with Open Makers Cube.
// If not, see <https://www.gnu.org/licenses/>.
//

include <BOSL/transforms.scad>
use <../printed/small_breadboard_holder.scad>
use <../vitamins/small_breadboard.scad>
include <NopSCADlib/core.scad> 





// ============ Constants ===============
IN = 25.4;
MM = 1;

PLANE_POS =  .02;
PLANE_NEG = -.01;
$fn = 30;

font_height = 7*MM;
3MM_TAP_HOLE = 2.5*MM;


// ============== Parameters ===============

body_x = 70*MM;
body_y = 61*MM;
body_z = 14*MM;

body_dim = [body_x, body_y, body_z];



inner_x = body_x + PLANE_POS ;
inner_y = 55*MM;
inner_z = 14*MM;

inner_notch_dim = [inner_x, inner_y, inner_z];

// spin plate

spin_plate_hole_ctoc_spacing_large = 22*MM;
large_hole_dia = 6*MM;
small_hole_dia = 3.2*MM;


tab_plug_dim  = [2.6*MM, 2*MM, 4*MM];
tab_notch_dim = [5*MM, 5*MM, 5*MM];



// scaling for 3D printers

HOLE_SIZE_COEF = 1.1;

NONE   = 0;
TEVO   = 1;
ENDER3 = 2;

3DPRINTER_SCALE = [
    [1, 1, 1], // NONE.  no rescaling
    [1, 1, 1], // TEVO
    [1, 1, 1]  // ENDER3
];


// ============== Render ==================


//small_bread_board_holder_3d_print_ready(NONE);
//small_bread_board_holder_3d_print_ready(TEVO);
//small_bread_board_holder_3d_print_ready(ENDER3);
//small_bread_board_holder();

//small_breadboard_assy();


// ============= Modules ==================

module small_bread_board_holder_3d_print_ready(scale_factor=NONE){

  scale(3DPRINTER_SCALE[scale_factor])
   small_breadboard_holder();
}




module small_breadboard_holder(){
  stl("small_breadboard_holder");

  color("orange"){

   difference(){
    base();
    hole_array_assy();
    hole();
    notches();
   }

   breadboard_text();
   plugs();

  }
}

module hole(){
  translate([body_x/2, body_y, 10*MM])
  rotate([90,0,0])
  scale(HOLE_SIZE_COEF)
  //#cylinder(d=3MM_TAP_HOLE, h=5*MM);
  zmove(-2) cylinder(d=3MM_TAP_HOLE, h=5*MM);
}


module notches(){
  translate([5*MM, -1, 6*MM])
    cube(tab_notch_dim);
  translate([body_x - tab_notch_dim[0] - 5*MM , -1, 6*MM])
    cube(tab_notch_dim);
}


module plugs(){
  translate([6*MM + .25*MM, body_y - 4*MM, 6*MM])
    cube(tab_plug_dim);
  translate([ (body_x - tab_plug_dim[0]) - 6*MM - .25*MM  , body_y - 4*MM, 6*MM])
    cube(tab_plug_dim);
}

module breadboard_text(){
    translate([35*MM, 41.5*MM, 1.5*MM ])
    linear_extrude(height=1.5)
    text("Breadboard", size=font_height, halign="center");
}

module hole_array_assy(){
 
 translate([13*MM, 0, 0])
    for (i = [0:2]){
      translate([i* spin_plate_hole_ctoc_spacing_large, 0, 0])
      hole_array();
    }

}

module hole_array(){
  spin_plate_holes_large();
  translate([0, spin_plate_hole_ctoc_spacing_large + 8.5*MM, 0])
  spin_plate_holes_small();
}

module spin_plate_holes_small(){

    translate([8*MM, 0, 0])

       scale(HOLE_SIZE_COEF)
        cylinder(d =small_hole_dia, body_z + 2*MM, center=true);
    
    mirror([1,0,0])
     translate([8*MM, 0, 0])
        scale(HOLE_SIZE_COEF)
        cylinder(d =small_hole_dia, body_z + 2*MM, center=true);

     translate([0, 8*MM, 0])
        scale(HOLE_SIZE_COEF)
        cylinder(d =small_hole_dia, body_z + 2*MM, center=true);
    
    mirror([0,1,0])
     translate([0, 8*MM, 0])
        scale(HOLE_SIZE_COEF)
        cylinder(d =small_hole_dia, body_z + 2*MM, center=true);

}

module spin_plate_holes_large(){

  //translate([13*MM, 8.5*MM,0])
  translate([0, 8.5*MM,0])
  rotate(90)
   for ( i = [0:2]){
     translate([i * spin_plate_hole_ctoc_spacing_large, 0, 0])
        scale(HOLE_SIZE_COEF)
        cylinder(d = large_hole_dia, body_z + 2*MM, center=true);
   }


}

module base(){
    difference(){

        cube(body_dim);
        translate([PLANE_NEG, 3.6*MM, 2*MM])
        cube(inner_notch_dim);

    }
}

// ============= Functions ==================

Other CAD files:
docs/corner_tube_connector_bottom_v2.stl
scad/back_spin_plate_assembly.scad
printed/arduino_uno_mounting_plate.scad
printed/armature_union.scad
printed/carry_handle.scad
printed/corner_lamp_holder.scad
printed/corner_tube_connector.scad
printed/din_rail_clip.scad
printed/handle_calibration.scad
printed/prop.scad
printed/raspberry_pi_mounting_plate.scad
printed/tray.scad
scad/arduino_uno_mounting_plate_assembly.scad
scad/corner_lamp_holder_assembly.scad
scad/corner_tube_top_assembly.scad
scad/din_rail_assembly.scad
scad/din_rail_clip_assembly.scad
scad/frame_assembly.scad
scad/handle_assembly.scad
scad/helping_hands_assembly.scad
scad/makers_cube.scad
scad/power_strip_assembly.scad
scad/prop_assembly.scad
scad/raspberry_pi_mounting_plate_assembly.scad
scad/small_breadboard_assembly.scad
scad/tray_assembly.scad
vitamins/alligator_clip.scad
vitamins/din_rail.scad
vitamins/dual_lock.scad
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

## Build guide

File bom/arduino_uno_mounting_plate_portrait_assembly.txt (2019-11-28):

arduino_uno_mounting_plate_portrait_assembly:
Vitamins:
  4 3MM threaded rivet insert
  1 Arduino Uno R3
  2 Screw M3 cap x 12mm
  1 Screw M3 cap x 16mm
  6 Screw M3 cap x 8mm

Printed:
  1 arduino_uno_mounting_plate.stl

Assemblies:
  1 back_spin_plate_assembly
  1 din_rail_clip_assembly

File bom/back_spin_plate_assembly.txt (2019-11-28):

back_spin_plate_assemblies:
Vitamins:
  8 3MM threaded rivet insert

Printed:
  4 back_spin_plate.stl

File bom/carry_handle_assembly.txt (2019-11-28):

carry_handle_assembly:
Vitamins:
  2 Screw M3 cap x 16mm
  2 Washer  M3 x 7mm x 0.5mm

Printed:
  1 carry_handle.stl

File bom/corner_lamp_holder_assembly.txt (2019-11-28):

corner_lamp_holder_assemblies:
Vitamins:
 12 Screw M3 cap x 12mm
  4 Screw M3 cap x 8mm

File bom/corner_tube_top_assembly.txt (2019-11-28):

corner_tube_top_assemblies:
Vitamins:
  4 3MM threaded rivet insert

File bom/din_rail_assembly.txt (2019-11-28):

din_rail_assembly:
Vitamins:
  7 35MM Din Rail 200 MM long
 14 Screw M3 cap x 8mm
 14 Washer  M3 x 7mm x 0.5mm

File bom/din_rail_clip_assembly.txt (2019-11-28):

din_rail_clip_assemblies:
Vitamins:
  8 3MM threaded rivet insert

Printed:
  4 din_rail_clip.stl

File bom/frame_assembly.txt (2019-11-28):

frame_assembly:
Printed:
  4 corner_tube_connector_bottom.stl

Assemblies:
  4 corner_tube_top_assemblies
  1 frame_bottom_assembly
  1 frame_middle_assembly
  1 frame_top_assembly

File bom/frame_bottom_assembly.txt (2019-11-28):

frame_bottom_assembly:
Vitamins:
  4 1IN Aluminum Square Tube 149.2 MM long
 20 3MM threaded rivet insert

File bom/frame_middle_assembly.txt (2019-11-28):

frame_middle_assembly:
Vitamins:
  4 1IN Aluminum Square Tube 149.2 MM long
 40 3MM threaded rivet insert

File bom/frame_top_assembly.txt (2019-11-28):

frame_top_assembly:
Vitamins:
  4 1IN Aluminum Square Tube 149.2 MM long
 40 3MM threaded rivet insert

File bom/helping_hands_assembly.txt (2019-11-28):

helping_hands_assembly:
Vitamins:
  2 Alligator Clip
  2 3MM Armature wire - 5 inches long
  2 Screw M3 cap x 12mm
  1 Screw M3 cap x 16mm
  6 Screw M3 cap x 8mm

Printed:
  2 armature_union.stl
  1 din_rail_clip.stl
  1 helping_hands_mount.stl

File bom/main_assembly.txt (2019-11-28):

main_assembly:
Vitamins:
  2  3M Dual lock velcro 149mm long
  2  3M Dual lock velcro 6mm long
  4 1 inch sq rubber foot
  1 Magnifier Lamp Assembly

Assemblies:
  1 arduino_uno_mounting_plate_portrait_assembly
  1 carry_handle_assembly
  4 corner_lamp_holder_assemblies
  1 din_rail_assembly
  1 frame_assembly
  1 helping_hands_assembly
  1 power_strip_assembly
  1 prop_assembly
  1 raspberry_pi_mounting_plate_portrait_assembly
  1 small_breadboard_landscape_assembly
  1 small_breadboard_portrait_assembly
  1 tray_assembly

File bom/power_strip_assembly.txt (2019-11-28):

power_strip_assembly:
Vitamins:
  2  3M Dual lock velcro 85mm long
  1  Super Danny 6 outlet Power Strip

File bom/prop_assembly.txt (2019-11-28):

prop_assembly:
Vitamins:
  2  3M Dual lock velcro 6mm long
  2 1 inch sq rubber foot

Printed:
  1 prop.stl

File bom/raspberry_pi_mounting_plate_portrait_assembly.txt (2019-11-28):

raspberry_pi_mounting_plate_portrait_assembly:
Vitamins:
  4 3MM threaded rivet insert
  1 Micro SD card
  1 Raspberry Pi 3
  2 Screw M3 cap x 12mm
  1 Screw M3 cap x 16mm
  6 Screw M3 cap x 8mm

Printed:
  1 raspberry_pi_mounting_plate.stl

Assemblies:
  1 back_spin_plate_assembly
  1 din_rail_clip_assembly

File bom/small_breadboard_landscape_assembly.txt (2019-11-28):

small_breadboard_landscape_assembly:
Vitamins:
  1 Small Breadboard
  2 Screw M3 cap x 12mm
  1 Screw M3 cap x 16mm
  1 Screw M3 cap x 5mm
  2 Screw M3 cap x 8mm

Printed:
  1 small_breadboard_holder.stl

Assemblies:
  1 back_spin_plate_assembly
  1 din_rail_clip_assembly

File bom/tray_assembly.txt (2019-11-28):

tray_assembly:
Vitamins:
  2 Screw M3 cap x 12mm
  2 Washer  M3 x 7mm x 0.5mm

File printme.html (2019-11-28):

# OpenMakersCube


Open Maker's Cube is an open source project developed for making electronics project design and testing more fun and convenient. Due to its versatile design, the Maker's Cube can be used for other hobbies and applications.

The itch needing scratching is the ratsnest of wires and cables generated when building electronics bread board circuits. I frequently use Raspberry Pis and other microcontrollers/SBCs. With these devices comes the need for power strips which quickly leads to a maze of entangled power cords.

Portability of any electronics project can be an issue. If a project is built on the kitchen table for example, relocating requires a lot of disconnecting and re-routing. Inevetibly wires came loose from the breadboards, resulting in needless troubleshooting.

Ergonomically, bending over and wiring breadboard circuits for hours is hard on the back and neck. Adequate Lighting can also be a concern.

The Maker's cube is lightweight. Around 3.5 lbs base unit only and is less than 7 lbs fully loaded with hardware(Rpi's/Arduinos, electronic components, plugin power supplies).

The dimensions are 200mm (8in.) x 200mm (8in.) x 200mm (8in.). This size is perfect for any desk or table. Not taking up any more space than a typical laptop.

The frame is made out of lightweight 1 in. square aluminum tubing. In early designs, 80/20 was used, but added almost 2x the weight.

M3 Threaded aluminum inserts are inserted into the aluminum frame to hold the components securely. The threaded inserts do require a rivet insertion tool. There are a lot of rivets, so inserting rivets into the frame is the most time consuming process.

All plastic parts (orange) are printed with PETG. I went with PETG to hopefully withstand the heat better. Especially in the summer months. Obviously, print in any material to fit your needs.

There are mounting plates to support Raspberry PIs and Arduino UNOs in both landscape and portrait orientations. Due to the flexibility of the DIN Rail clips, you can design any mounting plate for any device which can easily be attached to the DIN rail clips using two 2 - 3mm securing screws.

There is a mounting plate which holds a standard 400 pt solderless breadboard in both landscape and portrait orientations.

Mounted in the center of the Maker's cube is a 6 outlet power strip with 4 - 2.4A USB ports. This allows for mulitple electrical plugins inside the cube keeping the corded 'ratsnest' inside the body of the cube. The power strip has an extra long 9.8 ft cord.

By design, only M3 screws are used. This requires only a simple 2.5mm allen key, which I leave inside the tray. The DIN rail mounting clips can normally be removed by hand. However, if there are a lot of mounted components, the only other tool needed is a small flat tipped screwdriver to unlock the clips.

I use 6 inch plastic wire ties to keep the cables/wires organized inside the Maker's cube body.

There is a removable stand (prop) which is used to tilt the cube back at a 30 deg angle which allows the user to work at a comfortable eye level.

The detachable LED magnifier lamp is extremely handy. It is super bright and having a magnifier lens makes it extremely easy to see the intricate details.

As an after thought, I designed a crude helping hands assembly. It uses 3mm aluminum armature wire and conventional alligator clips. This is helpful if you need to solder or hold components. Yes, the wire will eventually break with excessive bending back-and-forth, but the wire is cheap and can be easily replaced.

I use 3M's 'Dual Lock' fastener tape to secure the power supply to the inside bottom frame of the cube. The allows the power supply to be easily removed if need be. Also, the front 'prop' stand which tilts the cube at an angle, uses small sections of this tape to secure itself inside the cube's inner frame for transport.

To be extremely modular and flexible I designed the DIN Rail clips to be generic by nature. There two 3mm threaded inserts for mounting external components. The idea is you can design and mount anything you'd like to the clip.

I began the CAD design work in Sketchup. However, since I wanted to release as a open source project, I migrated the CAD design over to OpenScad (http://openscad.org). I relied heavlily on these wonderful open source projects:
1. NopSCADlib (https://github.com/nophead/NopSCADlib/blob/master/readme.md) - nophead, thanks so much for contributing this library! Absolutely amazing and a huge time saver for generating this beautiful documentation. 2. BOSL (https://github.com/revarbat/BOSL/wiki) 3. Dimlines - A dimensioning library (http://www.cannymachines.com/entries/9/openscad_dimensioned_drawings) 4. objectarrays (https://github.com/mathcodeprint/openscad-fiddlybits/blob/master/objectarrays.scad) 5. MCAD (https://github.com/openscad/MCAD) 6. Obiscad (https://github.com/Obijuan/obiscad) 7. Textgenerator (https://www.thingiverse.com/thing:59817) 8. Shimonbox (https://github.com/ubitux/shimonbox) 9. Openscad-threads (http://dkprojects.net/openscad-threads/) 10. Chamfersfor OpenScad (https://github.com/SebiTimeWaster/Chamfers-for-OpenSCAD) 11. BOLTS (https://www.bolts-library.org/en/index.html) 12. Din Rail Inspiration (https://www.thingiverse.com/thing:101024) RobertHunt Thingiverse

Thank you to the authors of these libraries. I may not have used all them directly in this project, but have gained inspiration from all. I may have used other libraries which I have not given credit. If so, please contact me and I'll update the list. I'm relatively new to OpenScad programming, so my code is not perfect and not always fully parameterized.

In summary, Maker's Cube goal is to address the following concerns: 1. Portability Contain the electronics project in one location and easy to transport. A fully loaded cube weighs less than 6 lbs. 2. Less back strain You can comfortably work on your projects in a seated position, eliminating the need to bend over a table/desk for hours. 3. Less eye strain There is a flexible super bright LED lamp mounted to the cube with a 1.5X magnifier glass. 4. Modularity Due to the Clip-on DIN Rail system, components can be easily re-positioned/removed from the cube. 5. Project tidyness A 6 outlet power strip with 4 - 2.4A USB ports is located inside the base of the cube. This allows for mulitple electrical plugins inside the cube keeping the corded 'ratsnest' inside the body of the cube.

### Tools Required For Build:

1. 3D Printer
2. Threaded Insert Rivet Gun w/3mm mandrel (https://www.amazon.com/gp/product/B06XVB3MMG/ref=ppx_yo_dt_b_search_asin_title?ie=UTF8&psc=1)
3. 2.5mm Allen Key
4. Saw to Cut 1 in. aluminum tubing. Chopsaw, hacksaw, other.
5. Knife or razor blades
6. 5mm drill bit to drill holes for 3mm threaded inserts
7. Drill
8. 3mm x .5mm hole tap. To tap 3mm holes in 3D printed plastic.

### Parts List and Qty Per Build:

- See Table Of Contents

### Vendor List of Parts (aka vitamins):

- M3 Threaded Rivet Inserts (bag 100pcs) (https://www.amazon.com/gp/product/B07HKK364C/ref=ppx_yo_dt_b_search_asin_title?ie=UTF8&psc=1)
- Velcro - 3M Dual Lock 1in wide 6FT Long (https://www.amazon.com/gp/product/B07D2LYFM2/ref=ppx_yo_dt_b_search_asin_title?ie=UTF8&psc=1)
- PETG Filament - Orange 1Kg (1080 FT long) (https://www.amazon.com/gp/product/B014VM9ALM/ref=ppx_yo_dt_b_asin_title_o00_s00?ie=UTF8&psc=1)
- 6 Outlet power strip (SuperDanny) (https://www.amazon.com/gp/product/B077ZSC6RQ/ref=ppx_yo_dt_b_search_asin_title?ie=UTF8&psc=1)
- Breadboard - Half Size (pack 6 ea) (https://www.amazon.com/gp/product/B01NARN7SM/ref=ppx_yo_dt_b_search_asin_title?ie=UTF8&psc=1)
- Rubber Bumpers (pack of 20 ea) (https://www.amazon.com/gp/product/B01G5WX4M2/ref=ppx_yo_dt_b_search_asin_title?ie=UTF8&psc=1)
- Screws - M3 x 5 (pack of 100) (https://www.boltdepot.com/Product-Details.aspx?product=6377)
- Screws - M3 x 8 (https://www.boltdepot.com/Product-Details.aspx?product=6379)
- Screws - M3 x 12 (https://www.boltdepot.com/Product-Details.aspx?product=6381)
- Screws - M3 x 16 (https://www.boltdepot.com/Product-Details.aspx?product=6382)
- Washers - M3 (https://www.boltdepot.com/Product-Details.aspx?product=4513)
- Magnifier Lamp (https://www.amazon.com/gp/product/B019R1BN3U/ref=ppx_yo_dt_b_search_asin_title?ie=UTF8&psc=1)
- Armature Wire 3MM (32.8 ft copper/alum) (https://www.amazon.com/gp/product/B07CQL7Y5B/ref=ppx_yo_dt_b_search_asin_title?ie=UTF8&psc=1)
- Tygon Tubing 50FT 1/8" OD (cover alligator clips) (https://www.zoro.com/tygon-tubing-clear-18-in-inside-dia-50-ft-acf00006/i/G4124294/)
- Alligator Clips (Package of 50) (https://www.amazon.com/gp/product/B01D9BO4OO/ref=ppx_yo_dt_b_search_asin_title?ie=UTF8&psc=1)
- Plastic Ties Blk 6 in (pk 250) (https://www.amazon.com/gp/product/B0718T3FMF/ref=ppx_yo_dt_b_search_asin_title?ie=UTF8&psc=1)
- 2.5MM Allen Wrench (pk 100) (https://www.amazon.com/gp/product/B005SE78Z8/ref=ppx_yo_dt_b_search_asin_title?ie=UTF8&psc=1)
- Din Rails 200MM (20 Pak) (https://www.amazon.com/gp/product/B07HMW318D/ref=ppx_yo_dt_b_asin_title_o08_s00?ie=UTF8&psc=1)

### Picture Gallery

- 
- 
- 
- 
- 
- 
- 

### 3D Printing

All of the STL models for this project are located in the /stls subdirectory.

Getting these prints correct was a highly iterative process. Accuracy is the key to getting these components to fit properly. Make sure your printer is calibrated and X/Y print scaling is correct.

### 3D Print Settings

STL | Resolution | Infill % | Supports | Comments
arduino_uno_mounting_plate.stl | .3 | 20 | NO | STL file located in /stls directory
armature_union.stl | .3 | 100 | NO | STL file located in /stls directory
back_spin_plate.stl | .3 | 20 | NO | STL file located in /stls directory
carry_handle.stl | .3 | 20 | NO | STL file located in /stls directory
corner_tube_connector_bottom.stl | .3 | 20 | YES | STL file located in /stls directory
corner_tube_connector_bottom_v2.stl | .3 | 20 | NO | Alternate print orientation not requiring supports and stronger. STL file located in /docs directory
corner_tube_connector_top.stl | .3 | 20 | YES | STL file located in /stls directory
corner_tube_connector_top_v2.stl | .3 | 20 | NO | Alternate print orientation not requiring supports and stronger. STL file located in /docs directory
din_rail_clip.stl | .3 | 100 | NO | STL file located in /stls directory
helping_hands_mount.stl | .3 | 20 | NO | STL file located in /stls directory
prop.stl | .3 | 20 | NO | STL file located in /stls directory
raspberry_pi_mounting_plate.stl | .3 | 20 | NO | STL file located in /stls directory
small_breadboard_holder.stl | .3 | 20 | NO | STL file located in /stls directory

Main Assembly

## Table of Contents

1. Parts list
2. Prop Assembly
3. Power Strip Assembly
4. Tray Assembly
5. Corner Lamp Holder Assembly
6. Din Rail Clip Assembly
7. Back Spin Plate Assembly
8. Raspberry Pi Mounting Plate Portrait Assembly
9. Arduino Uno Mounting Plate Portrait Assembly
10. Small Breadboard Portrait Assembly
11. Small Breadboard Landscape Assembly
12. Carry Handle Assembly
13. Din Rail Assembly
14. Corner Tube Top Assembly
15. Frame Bottom Assembly
16. Frame Middle Assembly
17. Frame Top Assembly
18. Frame Assembly
19. Helping Hands Assembly
20. Main Assembly

## Parts list

Prop | Power Strip | Tray | Corner Lamp Holder | Din Rail Clip | Back Spin Plate | Raspberry Pi Mounting Plate Portrait | Arduino Uno Mounting Plate Portrait | Small Breadboard Portrait | Small Breadboard Landscape | Carry Handle | Din Rail | Corner Tube Top | Frame Bottom | Frame Middle | Frame Top | Frame | Helping Hands | Main | TOTALS
. | . | . | . | . | . | . | . | . | . | . | . | . | . | . | . | . | . | 2 | 2 | 3M Dual lock velcro 149mm long
2 | . | . | . | . | . | . | . | . | . | . | . | . | . | . | . | . | . | 2 | 4 | 3M Dual lock velcro 6mm long
. | 2 | . | . | . | . | . | . | . | . | . | . | . | . | . | . | . | . | . | 2 | 3M Dual lock velcro 85mm long
. | 1 | . | . | . | . | . | . | . | . | . | . | . | . | . | . | . | . | . | 1 | Super Danny 6 outlet Power Strip
2 | . | . | . | . | . | . | . | . | . | . | . | . | . | . | . | . | . | 4 | 6 | 1 inch sq rubber foot
. | . | . | . | . | . | . | . | . | . | . | . | . | 4 | 4 | 4 | . | . | . | 12 | 1IN Aluminum Square Tube 149.2 MM long
. | . | . | . | . | . | . | . | . | . | . | 7 | . | . | . | . | . | . | . | 7 | 35MM Din Rail 200 MM long
. | . | . | . | . | . | . | . | . | . | . | . | . | . | . | . | . | 2 | . | 2 | 3MM Armature wire - 5 inches long
. | . | . | . | 8 | 8 | 4 | 4 | . | . | . | . | 4 | 20 | 40 | 40 | . | . | . | 128 | 3MM threaded rivet insert
. | . | . | . | . | . | . | . | . | . | . | . | . | . | . | . | . | 2 | . | 2 | Alligator Clip
. | . | . | . | . | . | . | 1 | . | . | . | . | . | . | . | . | . | . | . | 1 | Arduino Uno R3
. | . | . | . | . | . | . | . | . | . | . | . | . | . | . | . | . | . | 1 | 1 | Magnifier Lamp Assembly
. | . | . | . | . | . | 1 | . | . | . | . | . | . | . | . | . | . | . | . | 1 | Micro SD card
. | . | . | . | . | . | 1 | . | . | . | . | . | . | . | . | . | . | . | . | 1 | Raspberry Pi 3
. | . | 2 | 12 | . | . | 2 | 2 | 2 | 2 | . | . | . | . | . | . | . | 2 | . | 24 | Screw M3 cap x 12mm
. | . | . | . | . | . | 1 | 1 | 1 | 1 | 2 | . | . | . | . | . | . | 1 | . | 7 | Screw M3 cap x 16mm
. | . | . | . | . | . | . | . | 1 | 1 | . | . | . | . | . | . | . | . | . | 2 | Screw M3 cap x 5mm
. | . | . | 4 | . | . | 6 | 6 | 2 | 2 | . | 14 | . | . | . | . | . | 6 | . | 40 | Screw M3 cap x 8mm
. | . | . | . | . | . | . | . | 1 | 1 | . | . | . | . | . | . | . | . | . | 2 | Small Breadboard
. | . | 2 | . | . | . | . | . | . | . | 2 | 14 | . | . | . | . | . | . | . | 18 | Washer M3 x 7mm x 0.5mm
| | | | | | | | | | | | | | | | | | | | 3D Printed parts
. | . | . | . | . | . | . | 1 | . | . | . | . | . | . | . | . | . | . | . | 1 | arduino_uno_mounting_plate.stl
. | . | . | . | . | . | . | . | . | . | . | . | . | . | . | . | . | 2 | . | 2 | armature_union.stl
. | . | . | . | . | 4 | . | . | . | . | . | . | . | . | . | . | . | . | . | 4 | back_spin_plate.stl
. | . | . | . | . | . | . | . | . | . | 1 | . | . | . | . | . | . | . | . | 1 | carry_handle.stl
. | . | . | . | . | . | . | . | . | . | . | . | . | . | . | . | 4 | . | . | 4 | corner_tube_connector_bottom.stl
. | . | . | . | 4 | . | . | . | . | . | . | . | . | . | . | . | . | 1 | . | 5 | din_rail_clip.stl
. | . | . | . | . | . | . | . | . | . | . | . | . | . | . | . | . | 1 | . | 1 | helping_hands_mount.stl
1 | . | . | . | . | . | . | . | . | . | . | . | . | . | . | . | . | . | . | 1 | prop.stl
. | . | . | . | . | . | 1 | . | . | . | . | . | . | . | . | . | . | . | . | 1 | raspberry_pi_mounting_plate.stl
. | . | . | . | . | . | . | . | 1 | 1 | . | . | . | . | . | . | . | . | . | 2 | small_breadboard_holder.stl

## Prop Assembly

### Vitamins

Qty | Description
2 | 3M Dual lock velcro 6mm long
2 | 1 inch sq rubber foot

### 3D Printed parts

1 x prop.stl

prop.stl

### Assembly instructions

prop_assembly

1. 3D print prop. See Print Settings
2. Using scissors, cut 2 ea 6mm x 1in strip of 3M dual lock velcro.
3. Remove adhesive backing from dual lock strips and attach to prop as indicated.
4. Remove adhesive backing from the 2 each rubber feet and attach to the bottom of the prop.

prop_assembled

## Power Strip Assembly

### Vitamins

Qty | Description
2 | 3M Dual lock velcro 85mm long
1 | Super Danny 6 outlet Power Strip

### Assembly instructions

power_strip_assembly

1. Using scissors, cut 2 each 1in x 85MM dual lock velcro.
2. Remove backing from dual lock strips and attach to the bottom of the power strip as indicated.

power_strip_assembled

## Tray Assembly

### Vitamins

Qty | Description
2 | Screw M3 cap x 12mm
2 | Washer M3 x 7mm x 0.5mm

### Assembly instructions

tray_assembly

1. Insert 2 ea. M3 x 12MM screws through two M3 flat washers.
2. Insert screw/washer assy through the front tray slots.
3. Secure tray to top frame assy.

tray_assembled

## 4 x Corner Lamp Holder Assembly

### Vitamins

Qty | Description
12 | Screw M3 cap x 12mm
4 | Screw M3 cap x 8mm

### Assembly instructions

corner_lamp_holder_assembly

1. 3D print 4 each lamp holder corner prieces. See Print Settings
2. Using a 3mm x .5mm hole tap, tap the back horizontal hole for the 8mm M3 screw. This screw will be used to secure the lamp in place.
3. Screw in 8mm screw a few turns.
4. When the frame assembly is assembled, use the remaining 3 12MM M3 screws to secure to frame corners.

corner_lamp_holder_assembled

## 4 x Din Rail Clip Assembly

### Vitamins

Qty | Description
8 | 3MM threaded rivet insert

### 3D Printed parts

4 x din_rail_clip.stl

din_rail_clip.stl

### Assembly instructions

din_rail_clip_assembly

1. 3D print 4 each din rail clips. See Print Settings
2. Using a threaded insert rivet gun, insert the rivets as indicated.
3. Using an M3 tap, tap the small center hole. This is optional and is be used to provide additional security of the din clip to the din rail.

din_rail_clip_assembled

## 4 x Back Spin Plate Assembly

### Vitamins

Qty | Description
8 | 3MM threaded rivet insert

### 3D Printed parts

4 x back_spin_plate.stl

back_spin_plate.stl

### Assembly instructions

back_spin_plate_assembly

1. 3D print 4 each back spin plates. See Print Settings
2. Using a threaded insert rivet gun, insert the rivets as indicated.

back_spin_plate_assembled

## Raspberry Pi Mounting Plate Portrait Assembly

### Vitamins

Qty | Description
1 | Screw M3 cap x 16mm
1 | Micro SD card
4 | 3MM threaded rivet insert
1 | Raspberry Pi 3
2 | Screw M3 cap x 12mm
6 | Screw M3 cap x 8mm

### 3D Printed parts

1 x raspberry_pi_mounting_plate.stl

raspberry_pi_mounting_plate.stl

### Sub-assemblies

1 x back_spin_plate_assembly | 1 x din_rail_clip_assembly
back_spin_plate_assembled | din_rail_clip_assembled

### Assembly instructions

raspberry_pi_mounting_plate_portrait_assembly

1. 3D print 1 each raspberry pi mounting plate. See Print Settings
2. Using a threaded insert rivet gun, insert the 4 rivets as indicated.
3. Attach Raspberry PI, backspin plate assy, and din rail clip assy together with screws.
4. 4 8MM screws secure the Raspberry pi to the mounting plate.
5. 2 8MM screw secure the raspbery pi mounting plate to the spin plate.
6. 2 12MM screws secure the spin plate to the din rail clip.
7. 1 16MM screw is optional and is used for additional security of the din rail clip to the din rail.

raspberry_pi_mounting_plate_portrait_assembled

## Arduino Uno Mounting Plate Portrait Assembly

### Vitamins

Qty | Description
1 | Screw M3 cap x 16mm
2 | Screw M3 cap x 12mm
4 | 3MM threaded rivet insert
1 | Arduino Uno R3
6 | Screw M3 cap x 8mm

### 3D Printed parts

1 x arduino_uno_mounting_plate.stl

arduino_uno_mounting_plate.stl

### Sub-assemblies

1 x back_spin_plate_assembly | 1 x din_rail_clip_assembly
back_spin_plate_assembled | din_rail_clip_assembled

### Assembly instructions

arduino_uno_mounting_plate_portrait_assembly

1. 3D print 1 each Arduino Uno mounting plate. See Print Settings
2. Using a threaded insert rivet gun, insert the 4 rivets as indicated.
3. Attach Arduino Uno, backspin plate assy, and din rail clip assy together with screws.
4. 4 8MM screws secure the Arduino Uno to the mounting plate.
5. 2 8MM screw secure the Arduino Uno mounting plate to the spin plate.
6. 2 12MM screws secure the spin plate to the din rail clip.
7. 1 16MM screw is optional and is used for additional security of the din rail clip to the din rail.

arduino_uno_mounting_plate_portrait_assembled

## Small Breadboard Portrait Assembly

### Vitamins

Qty | Description
1 | Screw M3 cap x 16mm
1 | Small Breadboard
1 | Screw M3 cap x 5mm
2 | Screw M3 cap x 12mm
2 | Screw M3 cap x 8mm

### 3D Printed parts

1 x small_breadboard_holder.stl

small_breadboard_holder.stl

### Sub-assemblies

1 x back_spin_plate_assembly | 1 x din_rail_clip_assembly
back_spin_plate_assembled | din_rail_clip_assembled

### Assembly instructions

small_breadboard_portrait_assembly

1. 3D print 1 each small breadboard holder. See Print Settings
2. Using a 3mm tap, tap the small horizontal hole located on the side of the breadboard holder.
3. 1 5MM screw secures the breadboard to the holder from the side.
4. 2 8MM screws secure the breadboard holder to the spin plate.
5. 2 12MM screws secure the spin plate to the din rail clip.
6. 1 16MM screw is optional and is used for additional security of the din rail clip to the din rail.

small_breadboard_portrait_assembled

## Small Breadboard Landscape Assembly

### Vitamins

Qty | Description
1 | Screw M3 cap x 16mm
1 | Small Breadboard
1 | Screw M3 cap x 5mm
2 | Screw M3 cap x 12mm
2 | Screw M3 cap x 8mm

### 3D Printed parts

1 x small_breadboard_holder.stl

small_breadboard_holder.stl

### Sub-assemblies

1 x back_spin_plate_assembly | 1 x din_rail_clip_assembly
back_spin_plate_assembled | din_rail_clip_assembled

### Assembly instructions

small_breadboard_landscape_assembly

1. 3D print 1 each small breadboard holder. See Print Settings
2. Using a 3mm tap, tap the small horizontal hole located on the side of the breadboard holder.
3. 1 5MM screw secures the breadboard to the holder from the side.
4. 2 8MM screws secure the breadboard holder to the spin plate.
5. 2 12MM screws secure the spin plate to the din rail clip.
6. 1 16MM screw is optional and is used for additional security of the din rail clip to the din rail.

small_breadboard_landscape_assembled

## Carry Handle Assembly

### Vitamins

Qty | Description
2 | Screw M3 cap x 16mm
2 | Washer M3 x 7mm x 0.5mm

### 3D Printed parts

1 x carry_handle.stl

carry_handle.stl

### Assembly instructions

carry_handle_assembly

1. 3D print 1 each carry handle. See Print Settings
2. Insert 2 each 16MM M3 screws into 2 each M3 washers.
3. Once frame assembly is assembled, attach carry hadndle to top of frame as indicated.

carry_handle_assembled

## Din Rail Assembly

### Vitamins

Qty | Description
14 | Screw M3 cap x 8mm
7 | 35MM Din Rail 200 MM long
14 | Washer M3 x 7mm x 0.5mm

### Assembly instructions

din_rail_assembly

1. Use M3 8MM screws and M3 washers to attach the din rail to the outer frame assembly.
2. Position the din rail in any position which works best for your project need.

din_rail_assembled

## 4 x Corner Tube Top Assembly

### Vitamins

Qty | Description
4 | 3MM threaded rivet insert

### Assembly instructions

corner_tube_top_assembly

1. 3D print 4 each corner tube connector tops . See Print Settings
2. Using a threaded insert rivet gun, insert the rivets as indicated.

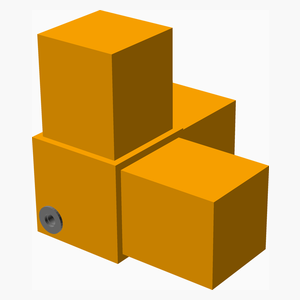
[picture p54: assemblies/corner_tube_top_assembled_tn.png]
corner_tube_top_assembled


## Frame Bottom Assembly

### Vitamins

Qty | Description
4 | 1IN Aluminum Square Tube 149.2 MM long
20 | 3MM threaded rivet insert

### Assembly instructions

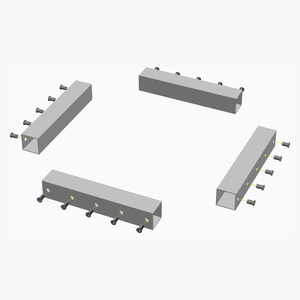
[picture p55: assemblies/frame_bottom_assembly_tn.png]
frame_bottom_assembly


1. Using a drill and a 5MM drill bit. Drill 5 each holes in each of the 4 rails (20 total). Drill pattern is below.
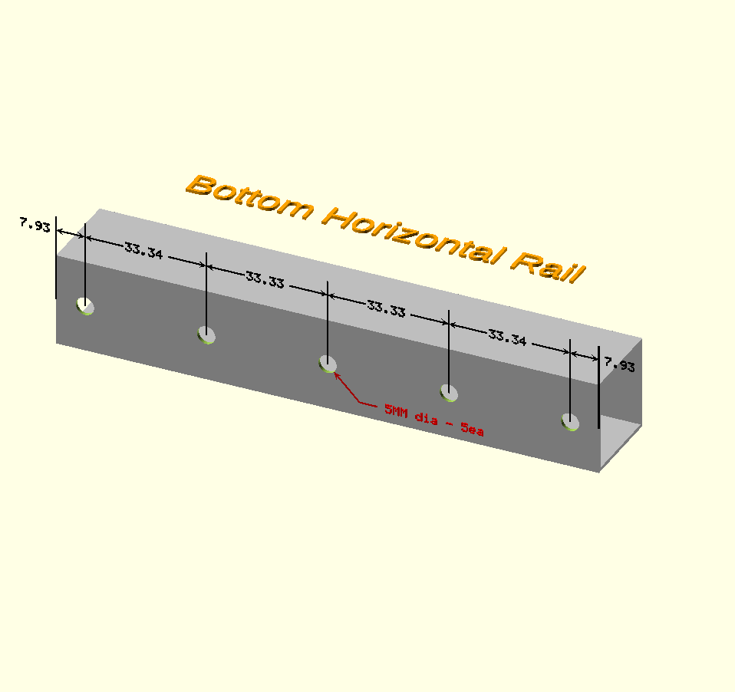
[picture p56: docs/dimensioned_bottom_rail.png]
2. Insert rivets using rivet gun. Do NOT insert the end rivets until the corner connectors are installed. 

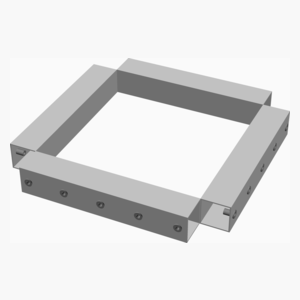
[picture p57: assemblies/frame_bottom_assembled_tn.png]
frame_bottom_assembled


## Frame Middle Assembly

### Vitamins

Qty | Description
4 | 1IN Aluminum Square Tube 149.2 MM long
40 | 3MM threaded rivet insert

### Assembly instructions

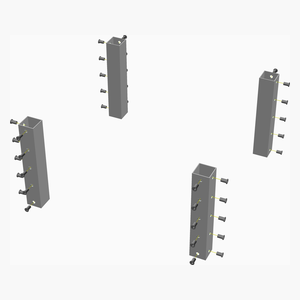
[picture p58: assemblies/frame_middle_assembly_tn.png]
frame_middle_assembly


1. Using a drill and a 5MM drill bit. Drill 10 each holes in each of the 4 rails (40 total). Drill pattern is below.
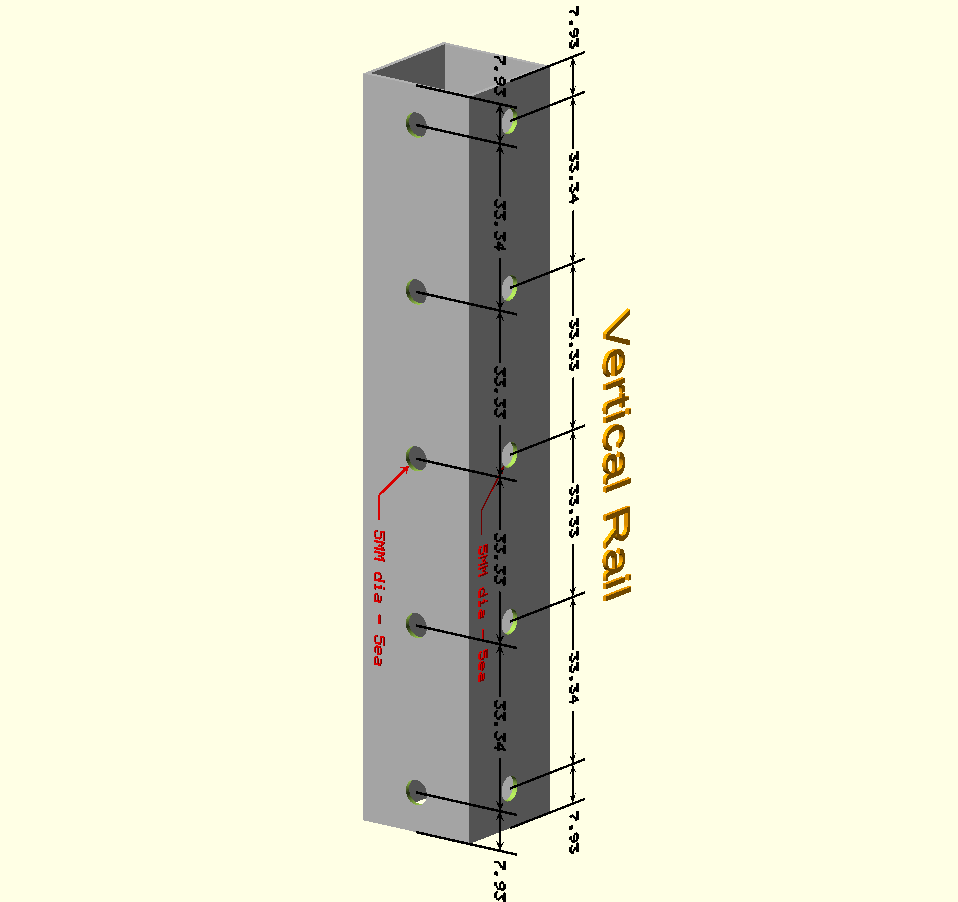
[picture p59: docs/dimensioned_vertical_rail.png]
2. Insert rivets using rivet gun. Do NOT insert the end rivets until the corner connectors are installed. 

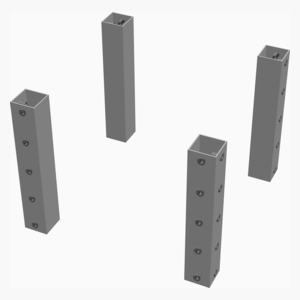
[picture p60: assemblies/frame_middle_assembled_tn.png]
frame_middle_assembled


## Frame Top Assembly

### Vitamins

Qty | Description
4 | 1IN Aluminum Square Tube 149.2 MM long
40 | 3MM threaded rivet insert

### Assembly instructions

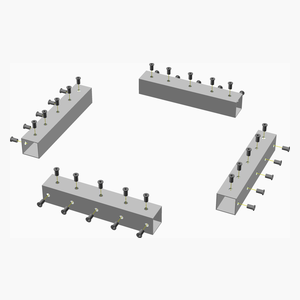
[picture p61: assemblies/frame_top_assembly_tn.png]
frame_top_assembly


1. Using a drill and a 5MM drill bit. Drill 10 each holes in each of the 4 rails (40 total). Drill pattern is below.
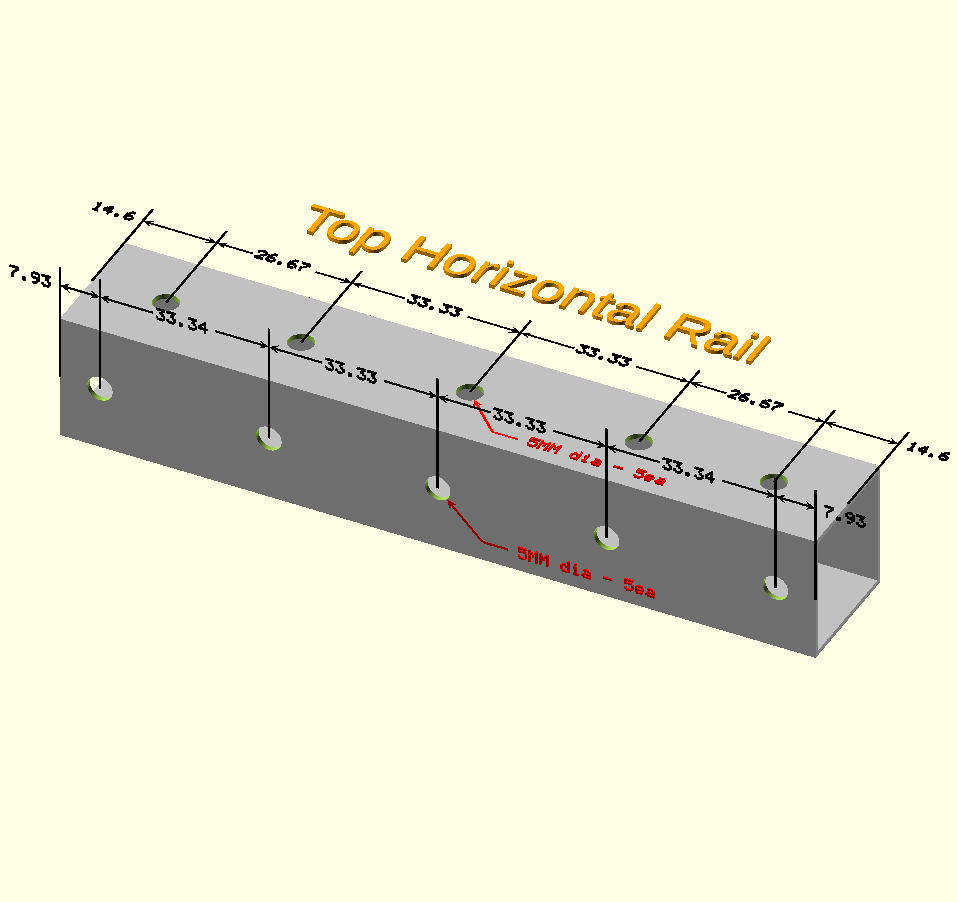
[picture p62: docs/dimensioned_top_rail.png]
2. Insert rivets using rivet gun. Do NOT insert the end rivets until the corner connectors are installed. 

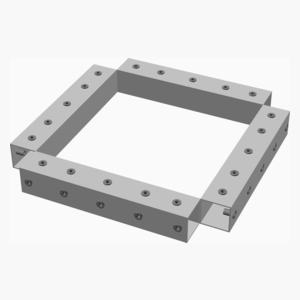
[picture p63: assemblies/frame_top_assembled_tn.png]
frame_top_assembled


## Frame Assembly

### 3D Printed parts

4 x corner_tube_connector_bottom.stl

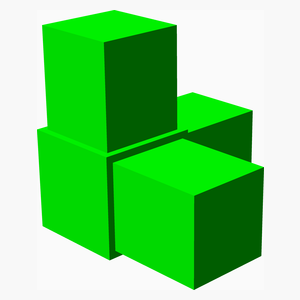
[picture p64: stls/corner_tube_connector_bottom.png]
corner_tube_connector_bottom.stl


### Sub-assemblies

4 x corner_tube_top_assembly | 1 x frame_bottom_assembly | 1 x frame_middle_assembly
corner_tube_top_assembled | frame_bottom_assembled | frame_middle_assembled

1 x frame_top_assembly

frame_top_assembled

### Assembly instructions

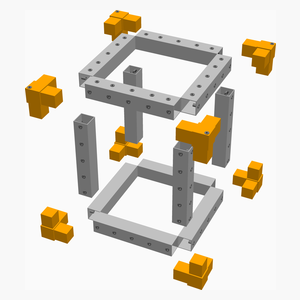
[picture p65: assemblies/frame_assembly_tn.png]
frame_assembly


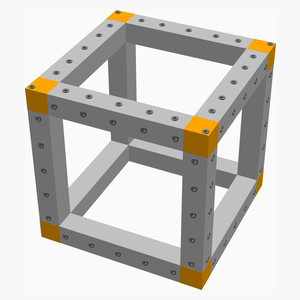
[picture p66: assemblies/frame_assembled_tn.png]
frame_assembled


## Helping Hands Assembly

### Vitamins

Qty | Description
2 | 3MM Armature wire - 5 inches long
2 | Alligator Clip
1 | Screw M3 cap x 16mm
2 | Screw M3 cap x 12mm
6 | Screw M3 cap x 8mm

### 3D Printed parts

2 x armature_union.stl | 1 x din_rail_clip.stl | 1 x helping_hands_mount.stl
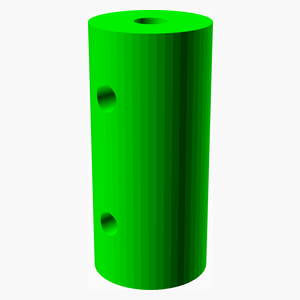
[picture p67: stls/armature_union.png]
armature_union.stl
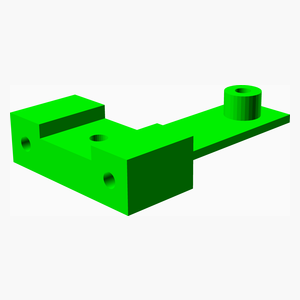
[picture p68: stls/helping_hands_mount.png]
helping_hands_mount.stl
 | din_rail_clip.stl | 

### Assembly instructions

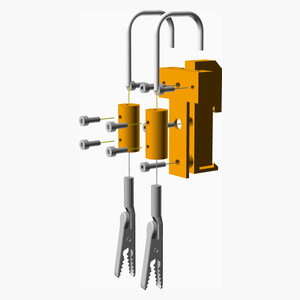
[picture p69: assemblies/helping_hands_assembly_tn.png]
helping_hands_assembly


1. 3D print 2 each armature union, din rail clip, and helping hands mount See Print Settings
2. Using a 3MM tap, tap the 4 holes of the armature unions.
3. Using a 3MM tap, tap the 2 holes located on the face of the helping hands mount.
4. Cut 2 each 5 inch sections of the 3MM armature wire.
5. insert one side of the armature wire into the armature union and an alligator clip into the other end of the armature union and secure with the 8MM screws.
6. Insert the other end of the 3MM armature wire into the helping hands mount and secure with a 8MM M3 screw.
7. Use the 2 12MM M3 screws to secure the helping hands mount to the din rail clip.

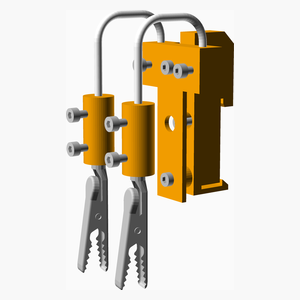
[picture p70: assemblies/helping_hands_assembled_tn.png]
helping_hands_assembled


## Main Assembly

### Vitamins

Qty | Description
2 | 3M Dual lock velcro 149mm long
1 | Magnifier Lamp Assembly
2 | 3M Dual lock velcro 6mm long
4 | 1 inch sq rubber foot

### Sub-assemblies

1 x arduino_uno_mounting_plate_portrait_assembly | 1 x carry_handle_assembly | 4 x corner_lamp_holder_assembly
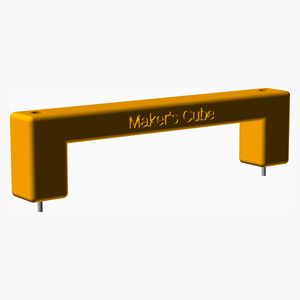
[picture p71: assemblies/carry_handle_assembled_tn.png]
carry_handle_assembled
arduino_uno_mounting_plate_portrait_assembled |  | corner_lamp_holder_assembled

1 x din_rail_assembly | 1 x frame_assembly | 1 x helping_hands_assembly
din_rail_assembled | frame_assembled | helping_hands_assembled

1 x power_strip_assembly | 1 x prop_assembly | 1 x raspberry_pi_mounting_plate_portrait_assembly
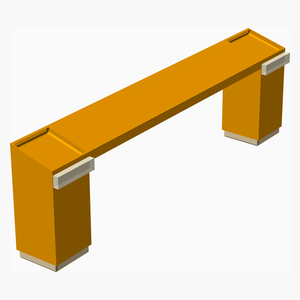
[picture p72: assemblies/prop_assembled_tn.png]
prop_assembled
power_strip_assembled |  | raspberry_pi_mounting_plate_portrait_assembled

1 x small_breadboard_landscape_assembly | 1 x small_breadboard_portrait_assembly | 1 x tray_assembly
small_breadboard_landscape_assembled | small_breadboard_portrait_assembled | tray_assembled

### Assembly instructions

main_assembly

1. Cut 2 each 149mm sections of dual lock velcro.
2. Remove dual lock backing and stick to the front and back inner bottom frame assembly. The power supply will stick to these velcro strips.
3. Attach 4 each rubber feet to the bottom 4 corners of the cube.
4. Cut 2 each 6mm sections of dual lock velcro.
5. Attach these small strips of velcro to the left inner frame where the prop will go when it is stored inside the cube.
6. Insert LED magnifying lamp into one of the 4 corner posts.
7. Attach all other assemblies as indicated.

main_assembled

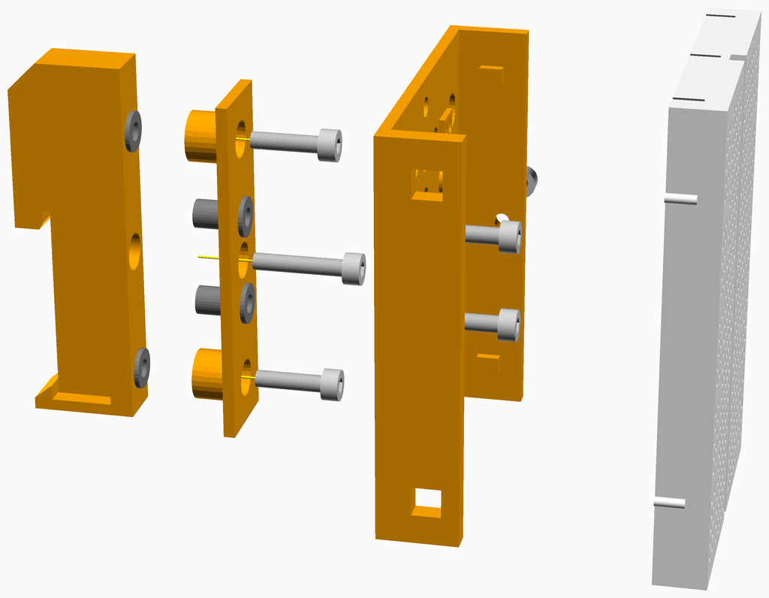
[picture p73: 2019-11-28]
assemblies/small_breadboard_portrait_assembly.png

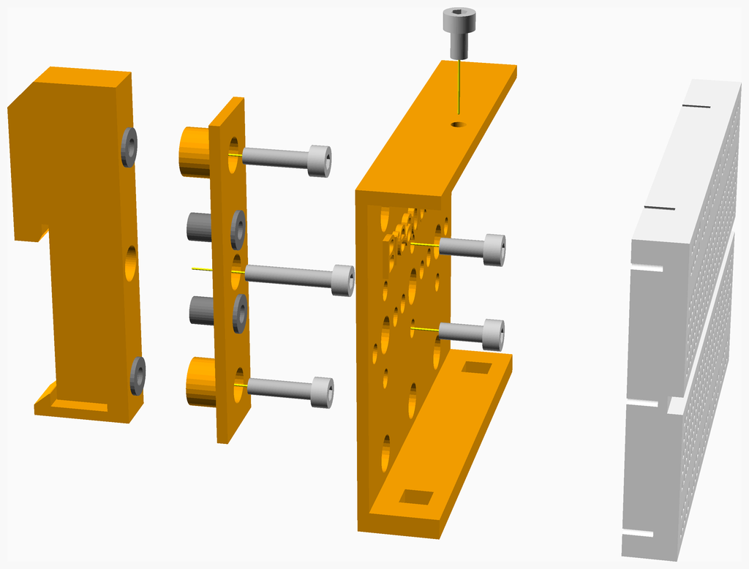
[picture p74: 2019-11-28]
assemblies/small_breadboard_landscape_assembly.png

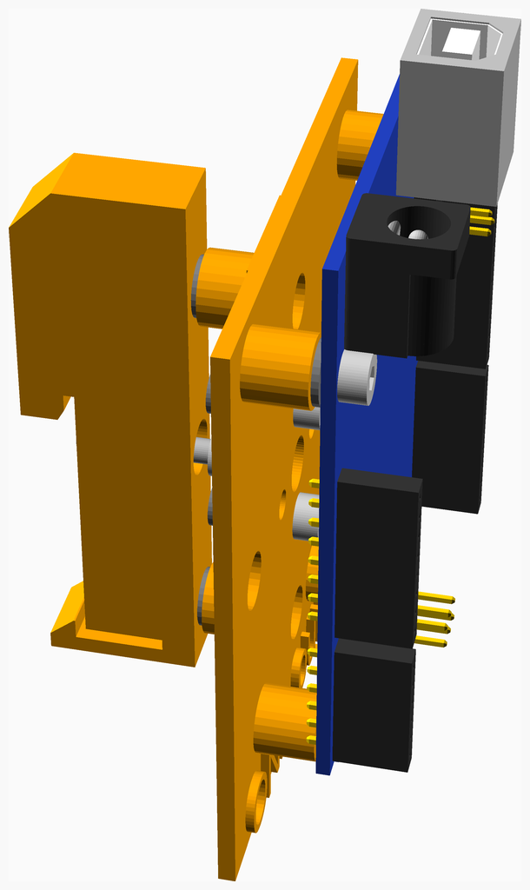
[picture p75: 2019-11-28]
assemblies/arduino_uno_mounting_plate_portrait_assembled.png

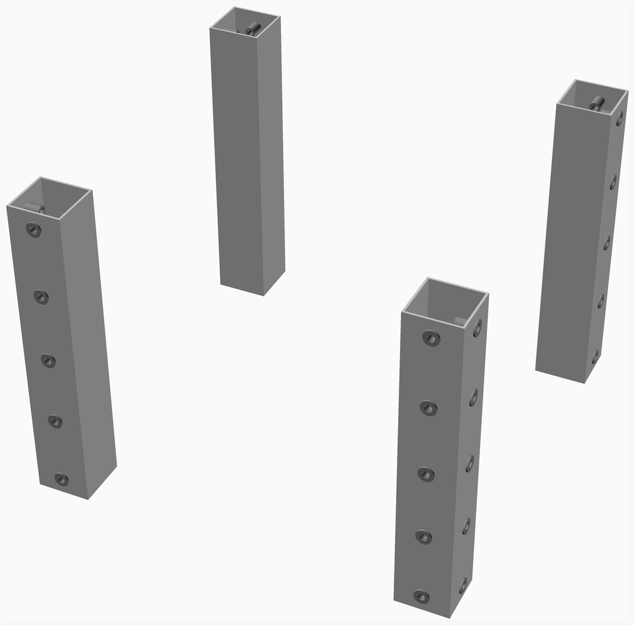
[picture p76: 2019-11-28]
assemblies/frame_middle_assembled.png

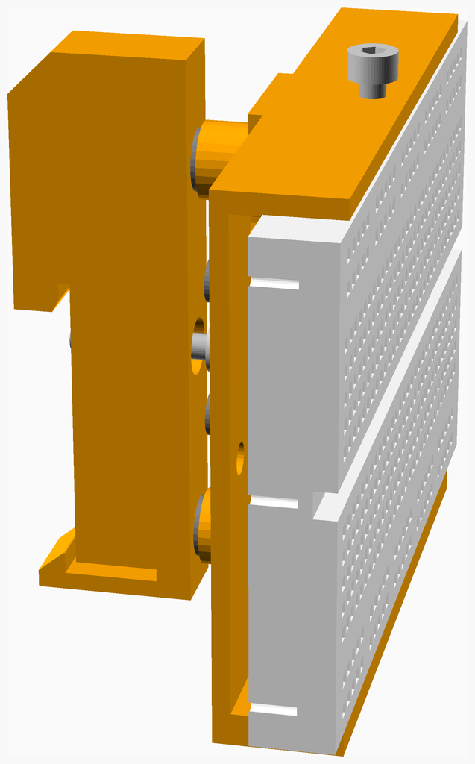
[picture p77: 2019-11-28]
assemblies/small_breadboard_landscape_assembled.png

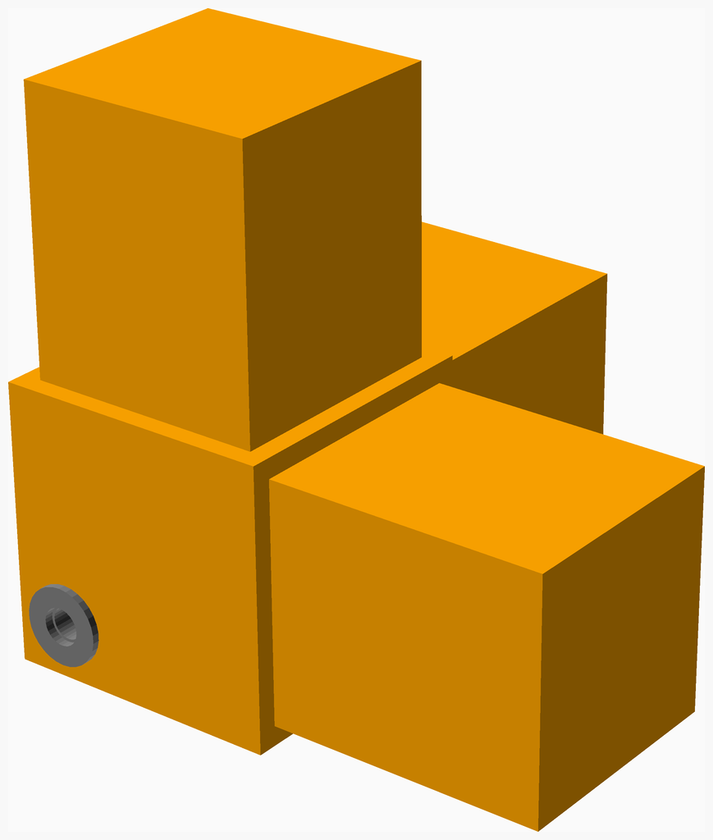
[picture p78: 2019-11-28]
assemblies/corner_tube_top_assembled.png
